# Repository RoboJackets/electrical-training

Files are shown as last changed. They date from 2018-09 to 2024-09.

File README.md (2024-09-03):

# RoboJackets Electrical Training

**Please bookmark this page!**

**Also, be sure to visit the RoboJackets Firmware Training page as well:** https://github.com/RoboJackets/firmware-training

Welcome to the source repository for the 2024 RoboJackets Electrical training program!

## Training Schedule 2024

* Time: 6:00pm - 7:30pm on Mondays and Fridays
* Bring: Your computer

Here is a breakdown of what electrical training is week-to-week:
* Week 0: Introductions, Electrical Basics*
* Week 1: Introduction to Prototyping and Arduino*
* Week 2: KiCAD Parts and Libraries
* Week 3: KiCAD Schematics
* Week 4: KiCAD Board Layout
* Week 5: Debugging and Soldering*

NOTE: Weeks 0, 1, will be joint sessions between electrical and firmware. Week 5 is a special session, usually held in the Hive. You get to practice surface mount soldering and debugging firmware on an actual PCB.

Location: 
* Week 0 (9/9 and 9/13): Van Leer C457
* Week 1 (9/16 and 9/20): Van Leer C457
* Week 2 (9/23 and 9/27): Skiles 169
* Week 3 (9/30 and 10/4): Skiles 169
* Week 4 (10/7 and 10/11): Skiles 169
* Week 5 (Date TBD): The Hive

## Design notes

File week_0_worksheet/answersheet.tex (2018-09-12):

\documentclass{article}
\usepackage{geometry}
\usepackage{flafter}
\geometry{letterpaper, portrait, margin=1in}

\usepackage{hyperref}
\hypersetup{
    colorlinks=true,
    linkcolor=black,
    filecolor=magenta,
    urlcolor=blue,
}

\usepackage{graphicx}
\graphicspath{ {images/} }

\usepackage{tcolorbox}
\usepackage{textcomp}
\usepackage{gensymb}
\usepackage{indentfirst}

\newcommand{\ans}{$\rule{1.5cm}{0.15mm}$}

\title{RoboJackets Electrical Training Week 0 Worksheet - Answer Key}
\author{Alex Xu \\ Joe Spall}
\date{\today\\v1.1}

\begin{document}
\maketitle{}
\setcounter{tocdepth}{2}
\tableofcontents

%Add Preface here

\pagebreak

\section{Introduction}
This is the Answer Key to the Week 0 worksheet. Only look at this sheet after you have given an honest attempt at \textbf{ALL} the questions. If you do not understand something from the worksheet, refer to your training instructors, classmates, and the additional information sheet provided.

\section{Intro to Electricity}
\begin{enumerate}
	\item Measured in Ohms ($\ohm$)
	\item $-3.3V-(-5V)=1.7V$
	\item Series, Parallel. Ammeter needs to be in series otherwise it will be shorted. Voltmeters essentially have infinite resistance and if placed in series will make the circuit an open circuit.
	\item $R=V/I=5V/0.2A=25\ohm$
	\item $P=V\dot I = 5V \times 0.2 A = 1W$
	\item $470\ohm \pm 5\%$
\end{enumerate}

\section{Capacitors and Inductors}
\begin{enumerate}
	\item Measured in Faraday ($F$)
	\item $C=Q/V=0.0025C/5V=0.0005F$
	\item False. Electrolytic capacitors have electrolytes inside and have polarity.
	\item False. Electrolytic capacitors are easier to achieve a higher capacitance than ceramics.
	\item Mitigating fluctuation in power supply.
	\item Henry ($H$)
	\item True. For example in solenoids and relays.
	\item False. Inductors are wires wrapped around a coil and display no special characteristics with DC.
\end{enumerate}

\section{Diodes and FETs}
\begin{enumerate}
	\item $5V/20mA=250\ohm$
	\item True. Lots of motors run at 12V and 24V and draw a lot of current while usual logic circuits runs at 5V or 3.3V and below with a very low current rating. Using FETs enables a logic circuit to use minimal power to control the flow of larger power.
	\item Q equals Vss. When A equals Vdd. The upper pFET opens and the lower nFET closes, connecting the output to ground.
\end{enumerate}

\section{Circuit Analysis}
\subsection{Parallel and Series}
	\begin{enumerate}
		\item $R=1/(1/(1.2\ohm+1.2\ohm)+1/3.6\ohm)=1.44\ohm$
		\item $ECHO\_OUT=91\ohm/(91\ohm+47\ohm)\times ECHO\_5V\approx 3.297V$
		\item $\Sigma C=(10\mu F+20\mu F+22\mu F+100\mu F)=152\mu F$
		\item $\Sigma C=1/(1/10\mu F+1/20\mu F+1/22\mu F+1/100\mu F)\approx 4.8672\mu F$
	\end{enumerate}
\subsection{Kirchoff's Law}
	\begin{enumerate}
		\item Let $i_1$ be the current going clockwise in the left loop, $i_2$ be the current through, $R_2$ from top to down and $i_3$ be the current going anti-clockwise in the right loop, then: \par
		$12V = 4\ohm \times i_1 + 3\ohm \times i_2$\par
		$8V = 2\ohm \times i_3 + 3\ohm \times i_2 $\par
		$i_1+i_3=i_2$\par
		solve for $i_1$, $i_2$ and $i_3$, get $i_3 \approx 2.15A$
	\end{enumerate}
	
	\begin{figure}[!h]
		\center
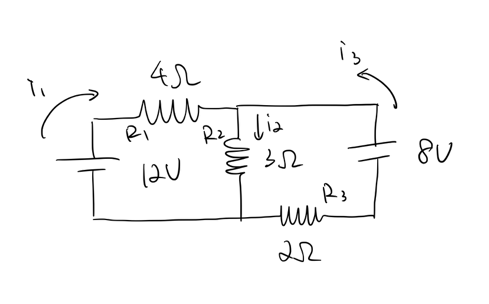
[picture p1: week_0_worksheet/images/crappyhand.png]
		
		\caption{Annotated Circuit}
		\label{fig:kirchoff_hand}
	\end{figure}

\section{Prototyping}
\begin{enumerate}
	\item Not connected, Connected, Not connected
	\item Single-core wire, should not. Twisting the wire essentially made the wire into single-core and made metal crimps harder to grab onto the wire.
	\item Pull-up resistor. To eliminate high impedance.
	\item False. This is a common joke in electrical engineering. The purpose of the fuse is to break to prevent high current levels from damaging the wires.
\end{enumerate}
\end{document}

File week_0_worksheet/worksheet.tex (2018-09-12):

\documentclass{article}
\usepackage{geometry}
\usepackage{flafter}
\geometry{letterpaper, portrait, margin=1in}

\usepackage{hyperref}
\hypersetup{
    colorlinks=true,
    linkcolor=black,
    filecolor=magenta,
    urlcolor=blue,
}

\usepackage{graphicx}
\graphicspath{ {images/} }

\usepackage{tcolorbox}
\usepackage{textcomp}
\usepackage{gensymb}
\usepackage{indentfirst}

\newcommand{\ans}{$\rule{1.5cm}{0.15mm}$}

\title{RoboJackets Electrical Training Week 0 Worksheet}
\author{Alex Xu \\ Joe Spall}
\date{\today\\v1.1}

\begin{document}
\maketitle{}
\setcounter{tocdepth}{2}
\tableofcontents
\pagebreak

\section{What is this worksheet? What's so special about it? Why should you read it?}
There are three documents in the Week 0 training: a worksheet, its answer sheet and an informational sheet that explains everything in this document. This document is the worksheet.
\vspace{6pt}\par
RoboJackets build robots, and we are going to help you understand how we built them so you can do it as well. The electrical training focuses on the idea of ``Prototyping", which requires a basic understanding of electricity. We therefore prepared Week 0 session for those have little knowledge in electricity so you'll walk in to Week 1 less confused. \vspace{6pt}\par
This worksheet contains all \textbf{a variety questions pertaining to information you should know when you walk into Week 1} electrical training session. It is perfectly fine if you do not know certain, or any, concepts covered in this worksheet. If there are any concepts in this worksheet you do not feel comfortable with, please ask any of the instructors or your classmates for help. For more background on the topics, you can also refer to the Informational Sheet. Please only refer to the Answer Sheet after you have attempted to answer all of the questions.\vspace{6pt}\par

\section{Intro to Electricity}
\begin{enumerate}
	\item Resistance is measured in \ans. (Unit)
	\item If the two terminals of a resistor are measured to be -3.3V and -5V with reference to some arbitrary pre-defined ground. The potential difference across the resistor is \ans.
	\item To measure current,an Ammeter is connected in \ans\ (parallel / series) with the desired path. To measure voltage, a Voltmeter is connected in \ans\ (parallel / series) with the desired path.
	\item 5V is applied across a resistor and the resultant current is 0.2A. The resistance across the resistor is \ans.
	\item The resistor in the previous question is dissipating energy at \ans W.
	\item With reference to the color coding diagram (Figure \ref{fig:Resistor}), a resistor of yellow, violet, brown and gold color code has a resistance of \ans.
	\begin{figure}
		\center
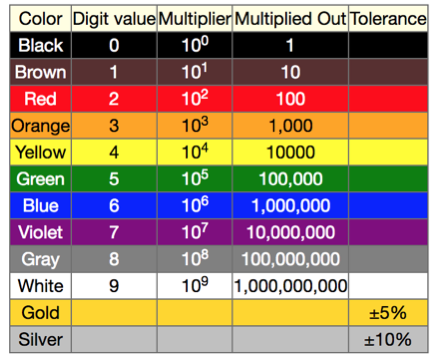
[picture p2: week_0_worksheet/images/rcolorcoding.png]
		
		\caption{Resistor Coding Chart}
		\label{fig:Resistor}
	\end{figure}
\end{enumerate}

\section{Capacitors and Inductors}
\subsection{Capacitors}
\begin{enumerate}
	\item Capacitors are measured in \ans. (Unit)
	\item 0.0025 coulomb of charge accumulates across a capacitor when 5V is applied, its capacitance is \ans.
	\item There are two types of capacitors: ceramic and electrolytic. Both of them do not have polarity (True / False).
	\item Electrolytic capacitors usually have a lower value than ceramic capacitors. (True / False)
	\item Capacitors are used in circuits for what purposes related to power?
\end{enumerate}
\subsection{Inductors}
\begin{enumerate}
	\item Inductors are measured in \ans. (Unit)
	\item Inductors can typically be found in electro-mechanical parts on a robot. (True / False)
	\item An ohmmeter is connected across an inductor and the meter reads zero ohms. The inductor is definitely broken. (True / False)
\end{enumerate}

\section{Diodes and FETs}
\begin{enumerate}
	\item LEDs are a type of diode, and they're very delicate. We need to apply additional resistors in series to an LED to prevent too much current. If the supply voltage is 5V and the LED is rated at 20mA maximum, what's the minimum resistance of the additional resistor?
	\item FETs are used to help low voltage logic circuits to control high voltage and current-drawing motors. (True / False)
	\item For the Figure \ref{fig:transistor}, assume the two transistors are functioning properly with respect to Vdd and Vss levels. What's the voltage level of Q when voltage at A equals Vdd?

	\begin{figure}[!h]
		\center
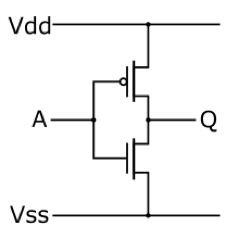
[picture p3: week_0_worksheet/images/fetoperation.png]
		
		\caption{Transistor Operation Schematics}
		\label{fig:transistor}
	\end{figure}
\end{enumerate}
\clearpage
\section{Circuit Analysis}
\subsection{Parallel and Series}
\begin{enumerate}
	\item Two $1.2 k \ohm$ resistors are in series, and this combination is in parallel with a $3.3 k\ohm$ resistor (left circuit in Figure \ref{fig:parallel}). The total resistance is \ans.
	\item Consider the right circuit in Figure \ref{fig:parallel}. Assume ECHO\_5V is actually 5V. What's the voltage at ECHO\_OUT?
	\item A $10 \mu F$, $20 \mu F$, $22 \mu F$, and $100 \mu F$ capacitor are in parallel. The total capacitance is \ans.
	\item Now the capacitors in Q3 are in series. Their capacitance is \ans.
	
	\begin{figure}[h]
		\center
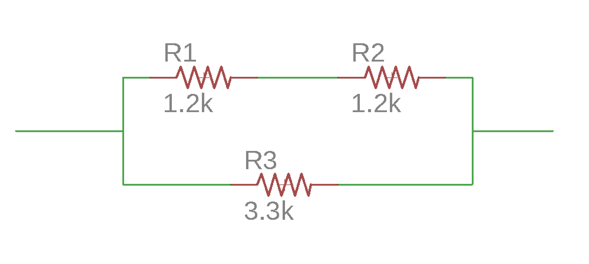
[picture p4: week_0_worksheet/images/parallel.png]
		
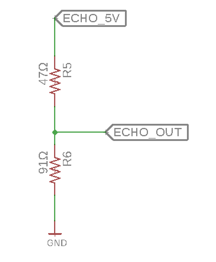
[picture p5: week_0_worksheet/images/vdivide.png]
		
		\caption{Parallel and Series Analysis}
		\label{fig:parallel}
	\end{figure}

\end{enumerate}
\subsection{Kirchoff's Law}
\begin{enumerate}
	\item In Figure \ref{fig:kirchof}, $R_1=4\ohm ,R_2=3\ohm,R_3=2\ohm, \varepsilon_1=12V, \varepsilon_2=8V$. What's the current through $ R_2 $.
	\begin{figure}[!h]
		\center
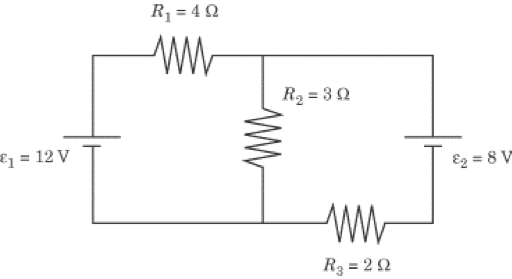
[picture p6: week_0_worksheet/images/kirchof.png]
		
		\caption{Kirchoff's Circuit Analysis}
		\label{fig:kirchof}
	\end{figure}
\end{enumerate}
\clearpage
\section{Prototyping}
\begin{enumerate}
	\item Breadboards are very useful during prototyping. If the breadboard in front of you is oriented so that the longer side faces you (see Figure \ref{fig:bread}). Holes in the same rows are \ans\ and those in the same column are \ans. Columns on the two sides of the middle trench are \ans\ (Fill in with Connected or Not connected). 
	\item When prototyping with breadboard, you should use \ans\ (single-core / multi-core) for a signal line. When crimping a multi-core wire, one (should / should not) twist the wire to make it more solid. 
	\item Is R1 in the right-sided circuit of Figure \ref{fig:bread} acting as a pull-down resistor or pull-up resistor? What does it do?
	\begin{figure}[h]
		\center
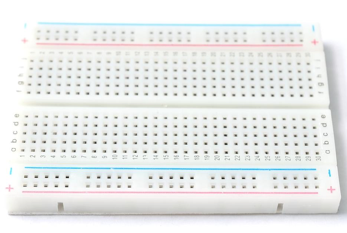
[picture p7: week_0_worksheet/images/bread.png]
		
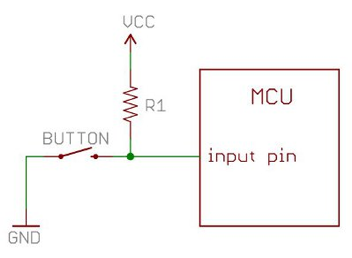
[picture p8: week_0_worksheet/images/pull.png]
		
		\caption{Example breadboard and pull-up resistor network}
		\label{fig:bread}
	\end{figure}
	\item Fuse is the most fragile part of your circuit. Replace it with a wire to make your circuit more robust (True / False).
\end{enumerate}
\end{document}

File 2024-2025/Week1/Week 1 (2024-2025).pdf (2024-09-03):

# Welcome!

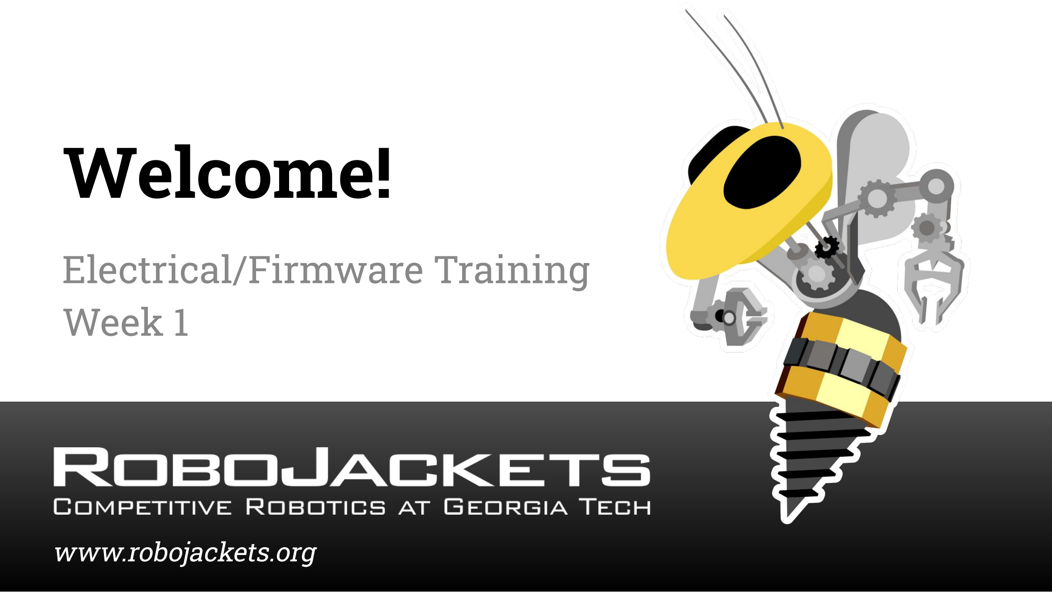
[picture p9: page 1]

## www.robojackets.org

# Electrical/Firmware Training Week 1

# - Introductions

# - What is RoboJackets Electrical/Firmware?

# - Logistics

# - Electrical Basics

# Last Week!

# This Week!

# - Microcontrollers & Firmware

# - Arduino, Part 1

# - Prototyping

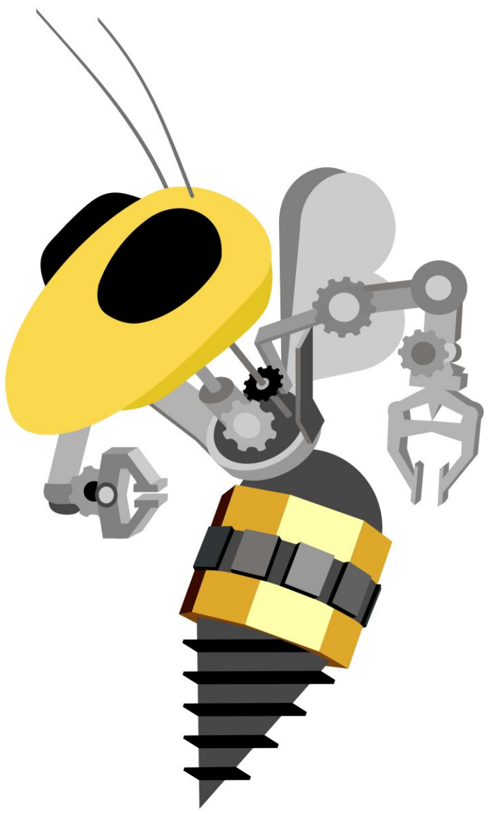
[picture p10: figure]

# Microcontrollers and Firmware

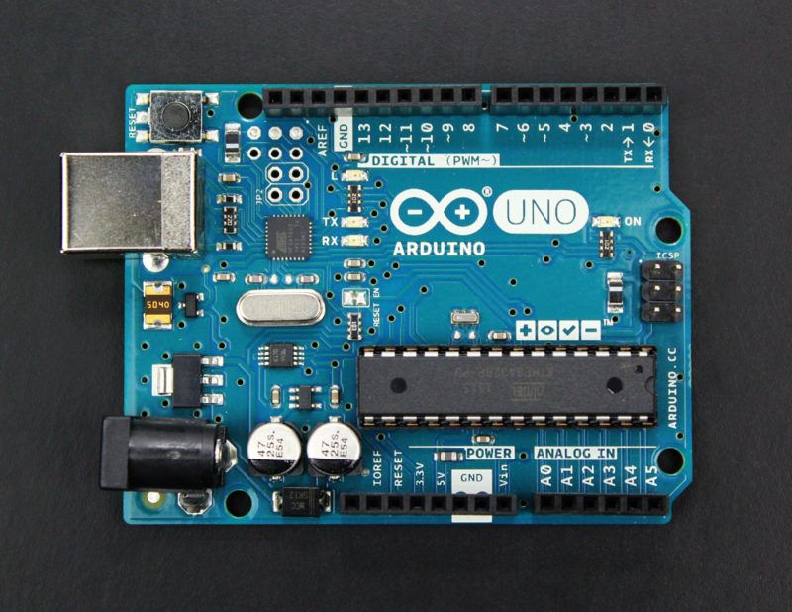
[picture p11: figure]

## - Arduino is…

- … a development board
(Arduino Uno, Arduino
Nano)
- … a programming
language (libraries,
compiler, syntax)

## - Development board centered around microcontroller

# Arduino!

# Programming a MCU

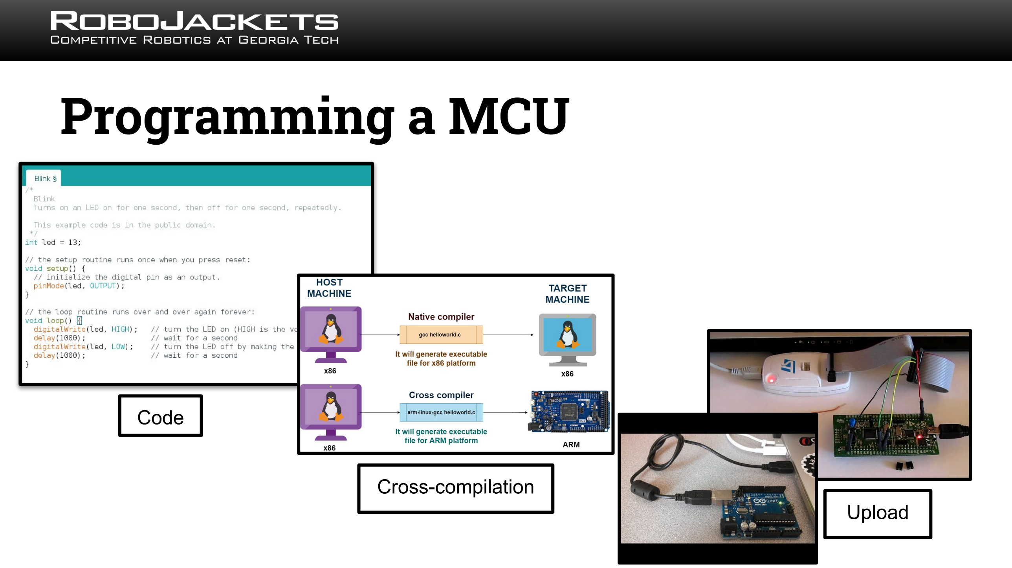
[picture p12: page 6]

Code

Cross-compilation
Upload

# Example: RoboWrestling

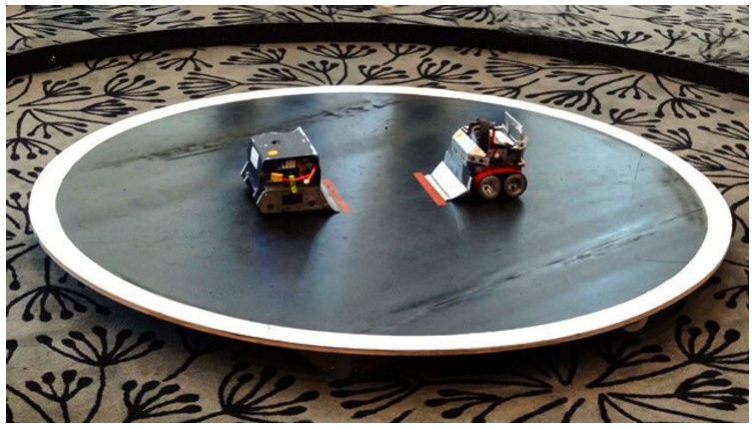
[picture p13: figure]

# High-level Decisions (Software)

- Where am I in the dohyo (ring)?
- Where is my opponent?
- Where should I move?
- If I made contact with the opponent, what should I do?

# Example: RoboWrestling

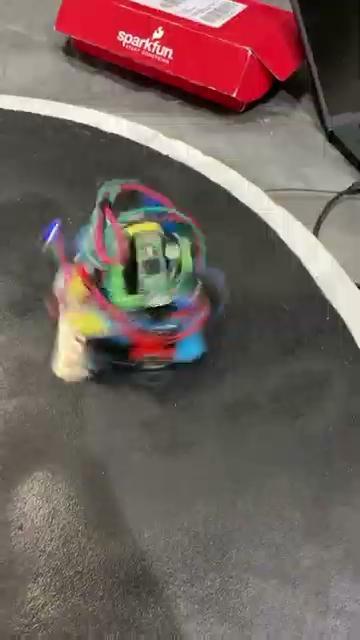
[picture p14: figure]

# Low-level Decisions (Firmware)

- How do I instruct the motors to spin at the desired speed?
- How do I instruct the robot to start?

## - Speed

- Counting encoder ticks <<< Computer vision algorithm

## - Space

- MCUs are small, PCs are not

## - Overkill

- Some robots don’t need to make complicated decisions
- PC would be $$$ to replace

## - Convenience

- Robotics hardware + software APIs cater to MCUs

# Why aren’t Low-level decisions made by a “software computer?”

# Prototyping

# Breadboard and Arduino Uno

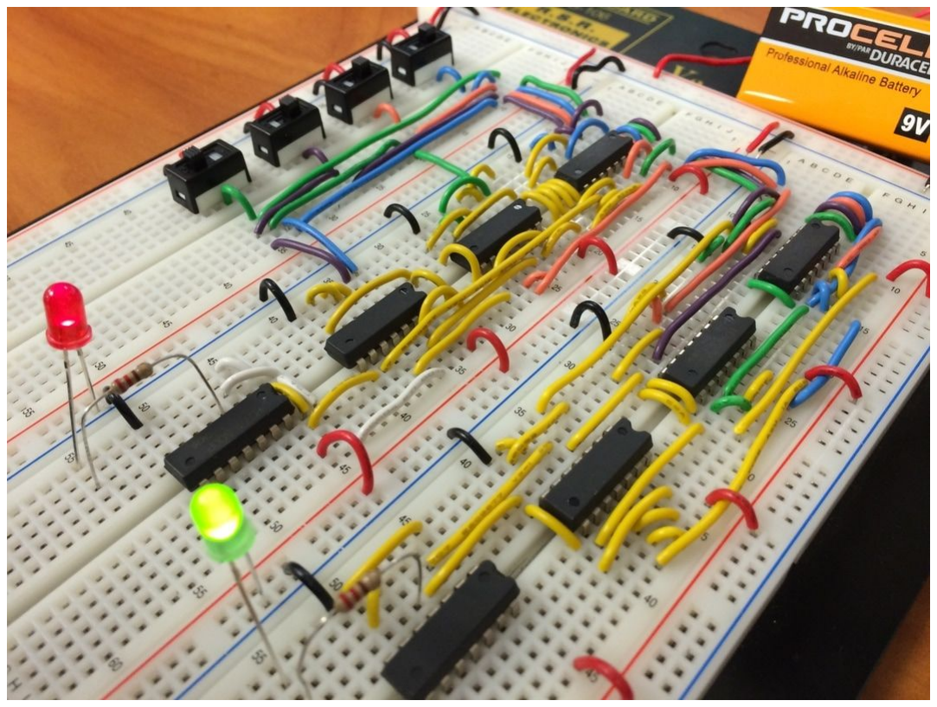
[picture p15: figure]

## - Solderless Breadboard (Top)

- Easy to change
- Good for initial prototyping
- Difficult to build large circuits

## - Protoboard (Middle)

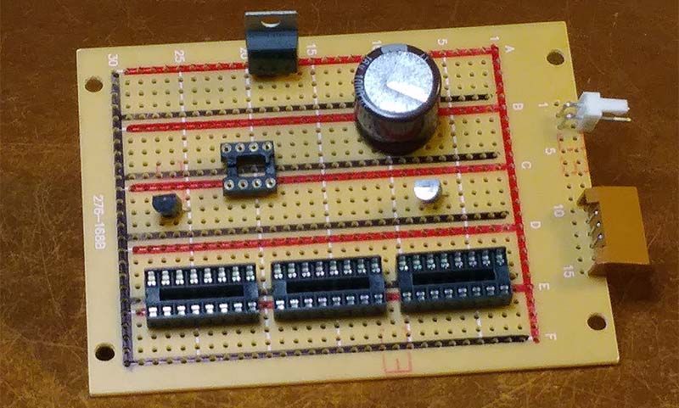
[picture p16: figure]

- More permanent; solder used
- Good for mature prototype
- Changes are doable, but involves re-soldering

## - Printed Circuit Board (Bottom)

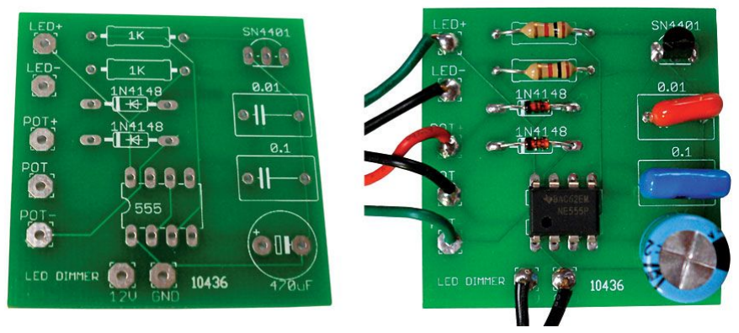
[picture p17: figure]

- Most permanent; unable to change connections
- Able to tightly pack components
- Circuit can span several layers
- Good for finished product

# From Breadboard to PCB

# Prototype basic circuit designs with Breadboards

Breadboards help you connect electrical components to build basic circuits.

### Terminals are the vertical columns. Each terminal is independent from the other

### Power rails are use to connect the power supply to the breadboard. The horizontal

pins on each power rail are connected.

Top half and bottom half of the breadboard are independent from each other.

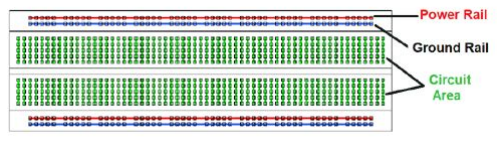
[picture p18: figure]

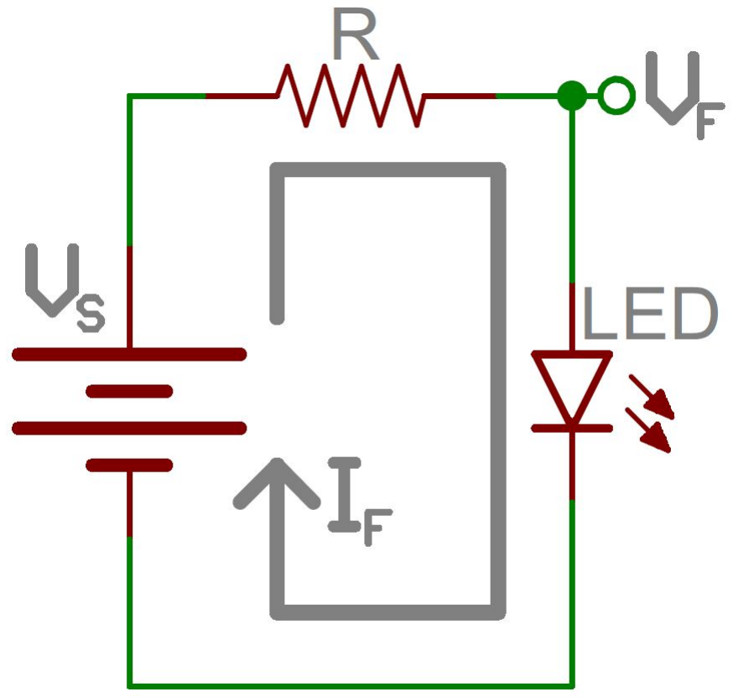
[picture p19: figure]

## - LEDs

- Diode: allows lots of current in one direction
- LED: too much current = blow up

## - Buttons

- Open / close a circuit
- Problem: High Impedance / “floating” pin

## - Resistors

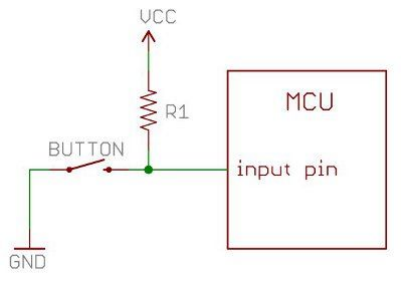
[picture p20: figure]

- Current-limiting resistor + LEDs (I = V / R)
- Pull-up resistor + Buttons

# Prototyping Hardware

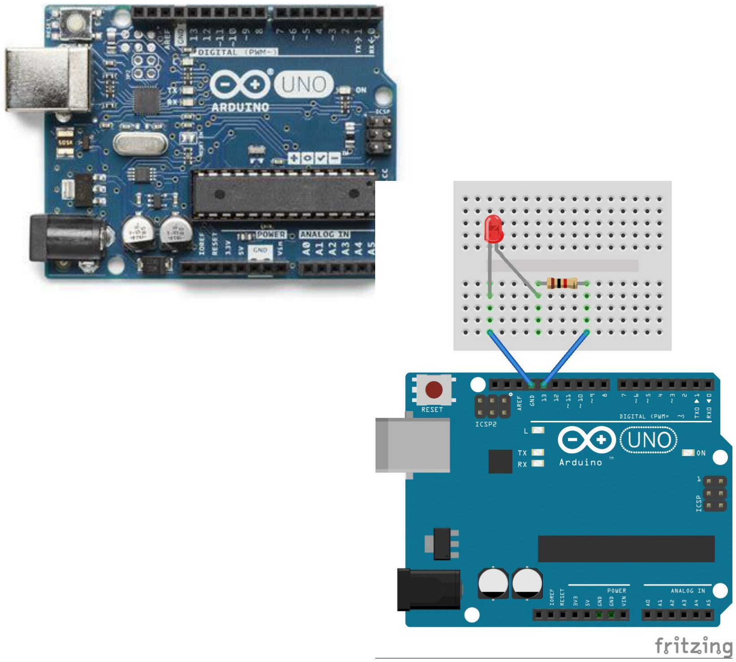
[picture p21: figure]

# Arduinos!

# Microcontroller with I/O ports to control electronics

# The pinout diagram

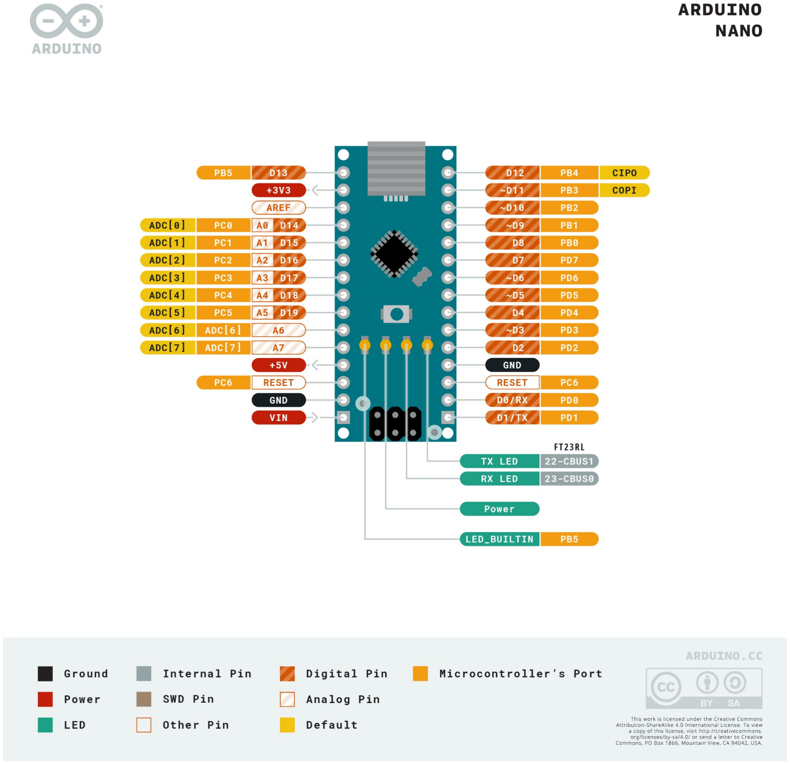
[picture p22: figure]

## - Arduino Nano Pinout - Physical pins -> software pins - Ex: D2 (hardware ) - -> “2” (software) - Some important pins:

## - PWM#: Digital (0 or 1) - A#: Analog (not restricted to 0 or 1) - VIN: Input voltage - If you’re not sure what a pin does, read the datasheet!

# Arduino IDE Explained

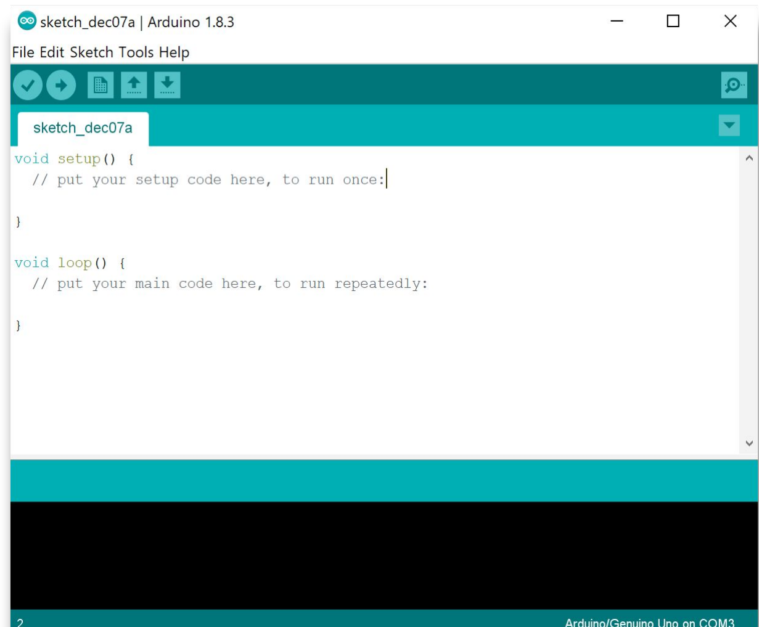
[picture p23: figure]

Verify checks for errors and compiles code

Upload compiles and uploads code

New creates new sketch

Save saves your sketch

### - IDE = “Integrated Development Environment”

- Programs = “sketches”.

Serial Monitor displays print outputs

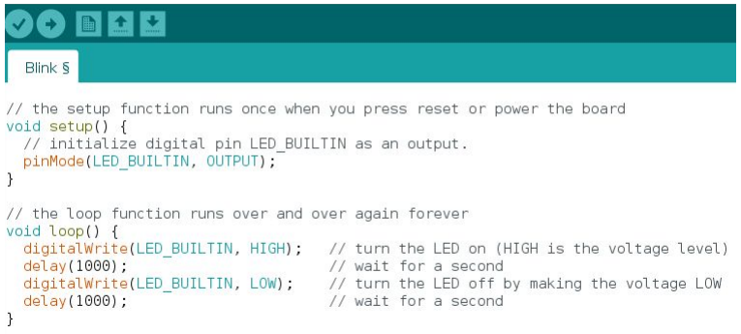
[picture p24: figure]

# - setup()

# - loop()

# - pinMode()

# - digitalWrite()

# - delay()

# Blink Example

# StateChangeDetection, Part 1


# - Variables

- Pin variables (buttonPin, ledPin)
- Integer variables

(buttonPushCounter, buttonState,

lastButtonState)

# - pinMode()

# - Serial.begin()

# StateChangeDetection, Part 2


# - digitalRead()

# - If /else

# - digitalWrite()

# Lab

# LEDs and Buttons

# Lab Time!


# - Read the lab setup

## - Legacy Arduino IDE - CH340 drivers - Challenges! - Blink - Blink + Button - Variable Frequency Blink + Button - Binary Counter

## Bring the following: - Laptop - Mouse (highly recommended unless you’re a menace with trackpad) - A Coke for Kyle

## Location: - Firmware: Skiles 255 (Monday) and Van Leer 457 (Friday) - Electrical: Skiles 169 (Monday and Friday)

# For next time…

# Feedback/Attendance


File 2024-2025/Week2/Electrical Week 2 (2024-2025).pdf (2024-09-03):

# Welcome!


www.robojackets.org

# Electrical Training Week 2

- What are Microcontrollers?
- Intro to C++
- Prototyping

# Last Week!

- Introduction to PCBs
- Introduction to KiCAD
- Parts and Libraries in KiCAD
- Configuring KiCAD Setup
- Adding parts to KiCAD

TLDR, we are going to import our parts into KiCAD from SnapEDA.

# This Week!

# What are PCBs?

# Printed Circuit Boards (PCBs)


- A way to construct more
electrically complex circuits
that are impractical for a breadboard
- Have a wide range of
components (sensors, MCUs, power circuit components)
that are often surface mount (SMD) rather than through
hole

Through Hole


Surface Mount

# Team


# Examples

## We use PCBs for a wide range of problems

# What is KiCAD?

## Where the suffering begins

# KiCAD


- Computer software to design PCBs
- Three Stages of Development
- Libraries & Parts (focus on this today!)
- Schematics
- Board Layout

# Project Manager


• Store various components used in projects • Schematic and footprint libraries are separate for electrical components in KiCAD • We will focus on the schematic library today; Libraries; Schematic; Library; Footprint Library


- Used in the schematic
view to make circuit
connections with other
component symbols
- “Symbolizes” the
connections made on the
PCB

# Symbol


- Used in the the board
layout view to make the
actual physical
connections between
components
- The component will
actually somewhat look
like the footprint

# Footprint


# Lab!

## KiCad Setup + Adding Parts to Schematic/Footprint Library

# Installing Software

- KiCAD
- Download here
- https://www.kicad.org/download/

- You could make your own parts, but why do that when someone else has already done it?
1. Go to snapeda.com (make an account if you haven’t done so)
2. Search up your part
3. Download the symbol and footprint and click the KiCad option
4. Inside the zip folder, there is a tutorial on how to import the symbol, follow the instructions for KiCad (or click on this link) (https://www.snapeda.com/about/import/#KiCad6)
- You will have to import the symbol and footprint separately
- Note: For footprint, you select the folder, not an actual file

# Downloading Parts from SnapEDA

- watch me embarrass myself

# Live Demonstration


- There are other symbol/footprint websites out there, so look around the internet!
- If you genuinely cannot find it, you can make your own inside KiCAD
- It’s a little advanced and somewhat niche, so I will not be going over it, but here is a link (https://github.com/RoboJackets/electrical-training/blob/master/labs/Week%202%20Lab%20(2023-2024).pdf) if you’re interested

# What if I can’t find my part?

# Thank You!

## Any Questions?

# For next time…

KiCAD Schematic! Be sure to bring:
- Your laptop
- Mouse (highly recommended)
- A Coke for your instructor (me)

Location:
- Electrical: Skiles 169
- Firmware: Van Leer C457

# Feedback/Attendance


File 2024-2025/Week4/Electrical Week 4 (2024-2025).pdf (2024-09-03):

# Welcome!


www.robojackets.org

# Electrical Training Week 4

# Last Week!

- Communication Systems
- KiCAD Schematics

1. Recap
2. Board Layout
a. Layers
b. Arranging components
c. Routing
d. Polygons
e. Lab!

# This Week!

- Previously studied Parts/Libraries and Schematics
- There are separate symbol and footprint libraries
- In schematics, we use nets to link pins on a symbol together to represent a device’s function

# Recap

# Board Layout


www.robojackets.org

# Place and route

- Physical placement of components on the PCB
- Replace the abstract nets from schematic with physical traces
- Access this feature by pressing the “Open PCB in board editor” button at the top of your schematic window or opening the PCB editor from the Project Manager window

# Board Layout

# PCB Structure

Copper; Soldermask; Silkscreen; Pads

Color | Layer Name | Layer Purpose
| F.Cu | Top/front layer of copper
| B.Cu | Bottom/back layer of copper
| Edge.Cuts | Outline of the board
| F.Silkscreen | Silkscreen for top
| B.Silkscreen | Silkscreen for bottom
| F.Fab | Top/front documentation layer (just for reference)

NOTE: Pads (SMD and through-hole) are part of footprints and vias are not part of any layer


# Changing Layers

## Select the layer you want to edit

# Assign


# Footprints to Symbols

## This must be done from the Schematic Editor

# Assign Footprints to Symbols

1. At the top, click Tools -> Assign Footprints
2. Match the schematic symbol to the PCB footprint that you want
- You can search the footprint you want in the search bar
- KiCAD doesn’t have the footprint for all parts, so you will have to download them from SnapEDA or make them yourself beforehand

## This is in the PCB Editor

# Board


# Generation


- Click on part and drag to move parts around
- Press ‘R’ to rotate
- Position components on the board area

# Arranging Components

- Minimize airwires (the unrouted wires)
- Collection of all airwires is ratsnest
- Maximum size of board
- Clearance between mounting holes and components
- Location of specific components
- Connectors on board edge
- Decoupling capacitors near decoupled pins
- Communicating/related components near one another

# Arrangement Considerations


- Leave some space
- Room for traces
- Room to solder
- Minimize the number of
intersecting airwires
- Easier to route traces

# Arranging Components


- Use the Route tracks
command in the right bar
- Left click on starting
point and left click on
end point
- Follow start and end of
airwire
- Routing angle of 45
degrees

# Drawing Traces


- Press “v” to change the
layer and put a via
- You can also right click, then click on “Place a
via”

# Changing Layers


- Allows you to fill a drawn area with copper connected to a specific net
- Useful to make “ground
planes”
- Click on “Add a filled zone”
- Then draw a shape such
as a rectangle or polygon
- Fill the polygon with Edit > Fill All Zones

# Filled Zone

Design Rules
Predefined rules that your board layout should follow to be correctly manufactured.
DRC (Design Rules Checker)
This tool will check if your board layout is attending to all of the design rules and notify you accordingly.

Note: Load Design Rules early on your design.

# Design Rules and DRC


Preview
- Make sure the silkscreen looks good (Both top and bottom side) Board
- Shows board properties: height, width, area, layers, board thickness, etc

# Gerber Viewer

- Start a new board layout
- Set up the dimensions
- Arrange the components
- Connect the traces
- Touch-up the silkscreen
- Check your design with DRC

For more information, access the LAB Document on GitHub.

# Lab Summary

- Watch me embarrass myself

# Live Demonstration


KiCad Getting Started:
https://docs.kicad.org/7.0/en/getting_started_in_kicad/getting_started_in_kicad.html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 (https://docs.kicad.org/7.0/en/getting_started_in_kicad/getting_started_in_kicad.html) How to branch on GIT:
https://github.com/RoboJackets/robocup-firmware/blob/master/doc/Git.md (https://github.com/RoboJackets/robocup-firmware/blob/master/doc/Git.md)

# Resources

We will be soldering! Please bring the following things:
- Yourself
- Computer/Laptop
- A Coke for Kyle

Location: The HIVE
When: TBD (sorry)

# For next time…

# Feedback/Attendance


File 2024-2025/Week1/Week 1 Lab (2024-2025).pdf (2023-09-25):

# RoboJackets Electrical / Firmware Training Week 1

Andrew Roach

September 25, 2023
v1.1

## Contents

1 Before You Start | ii
2 Background | iii
3 Objective | vii
4 Appendix | ix

i

## 1 Before You Start

### 1.1 Prerequisites

Before diving into the lab, make sure you have followed the Setup Instructions, which can be found on the RoboJackets Electrical Training GitHub page. After completing the setup instructions, verify that you have the following:

- The Legacy Arduino IDE (version 1.8.X, NOT 2.X!).
- A working Arduino Nano. When you plug the Nano into your computer, the LED labeled “POW” should illuminate.
- The CH340 drivers. If you installed the drivers correctly, the Arduino Nano should appear when you click on Tools > Port in the Arduino IDE.

### 1.2 Setup

Before you can upload code to the Arduino Nano, you need to tell the Arduino IDE what hardware you are using. To configure this, set the following settings in the Tools menu:

- Board: Arduino Nano
- Processor: ATMega328P (Old Bootloader)

– If this fails, try ATMega328P

- Port: select the port the Arduino Nano is plugged into.

– On Windows, check the “Ports” section in Device Manager

– On Linux, check for devices starting with /dev/ttyACM* or /dev/ttyUSB*.

- Programmer: AVPISP mkII


Figure 1: A properly configured Arduino IDE. Note that the “Port” value will be different.

ii

## 2 Background

The goal of this lab is to get you acquainted with prototyping with Arduinos. First, you must understand the hardware you are working with. Next, you will learn how to write and upload software onto an Arduino. Finally, we will give a brief introduction into the Arduino programming language. At the end, you will be tasked with implementing some basic circuits involving LEDs, resistors, and pushbuttons.

### 2.1 The Arduino Nano

Figure 2 depicts the pinout diagram for the Arduino Nano. The pinout diagram summarizes the capabilities of the Arduino Nano and depicts the mapping between the physical pins on the microcontroller and the aliases given to the physical pins in software. For example, the digital pin “D2” is represented by the integer “2” in an Arduino program.
For this lab, we will be primarily focused on the digital pins, D0 - D19. The digital pins operate in a binary fashion; they send and receive signals as a logical HIGH or a logical LOW. Since the Arduino Nano operates on 5V logic, logical HIGH corresponds to 5V, while logical LOW corresponds to 0V.


Figure 2: Pinout for Arduino Nano. The “Digital Pin” numbers (D2, D3, etc...) correspond to the numbers used in functions such as pinMode and digitalWrite.

iii

Figure 2 also depicts some pins that can’t be interacted with via software, but are useful nonetheless. The +3V3 and +5V pins provide power, while the GND pins provide a ground reference. The VIN pin stands for “Voltage In”, and it is used to supply 5V externally when you aren’t providing the microcontroller power over USB. The “Reset” pins are used to restart the program on the Arduino Nano using an external signal.
The Arduino Nano also has some useful features besides its pins. The button in the middle of the Arduino Nano causes the program on the Arduino Nano to restart. The “Power” LED illuminates when the Arduino Nano is being powered by 5V. The LED labeled “LED BUILTIN” is an LED that can be controlled via software. You can address it using the LED_BUILTIN macro in your program.

### 2.2 Electrical Hardware

The solderless breadboard shown in Figure 3 is your workspace when prototyping. The power rails labeled with “+” and “-” are connected horizontally and is ideal for distributing 5V and GND. The terminal strips in the middle of the solderless breadboard are connected vertically. The center divider separates the terminal strips on either side of breadboard from one another.
Jumper wires are useful for carrying electrical signals between different vertical terminal strips or between the power rails and the vertical terminal strips. Resistors are useful in conjunction with LEDs and pushbuttons. LEDs will burn themselves out if they are given too much current. The voltage drop across an LED is constant, so by increasing the resistance of the LED by using a resistor in series with an LED, the current drops. Resistors are also used with buttons to ensure the output of the button is never floating. See the appendix for more details.


Figure 3: Anatomy of a solderless breadboard.


Figure 4: An example of how to lay out a circuit on a breadboard. The Arduino Nano straddles the center divider, providing power to the power rails. The resistor, LED, and button are laid out across different terminal strips and are connected using jumper wires.

iv

### 2.3 The Arduino IDE

We will summarize a couple of important features for getting started with the Arduino IDE.

### 2.3.1 Sketches and Examples

User-created programs in the Arduino IDE are called sketches. The Arduino IDE also provides some built-in example sketches under File > Examples. Some useful examples for this lab are “Blink” under “Basics” and “Button” under “Digital”. You cannot modify examples, but you can use them as a starting points for your sketches.


Figure 5: Accessing the Arduino IDE’s built-in examples under File > Examples.

### 2.3.2 Verifying and Uploading Code

Once you have written your Arduino program, you have to do two things before your code is running on the Arduino Nano.

- Verify (checkmark button): This compiles your code into an executable format for the microcontroller. Compilation will fail if you have made a syntax error in your program. You do not need to be plugged into the microcontroller to Verify your program.
- Upload (arrow button): This uploads your code onto the microcontroller plugged into your computer. Uploading may fail if your settings in the “Tools” menu is incorrect; if you are having issues uploading to the microcontroller, go back to Section 1.2 and verify your settings are correct! The program will begin running immediately after it finishes uploading.

Figure 6: The Verify (checkmark) and Upload (rightward-facing arrow) buttons in the Arduino IDE.

v

### 2.3.3 The Arduino Programming Language

The Arduino Programming language is similar to C++. Below, we have listed some useful functions for this lab:

- setup(): setup() is called when the program starts. It will run once when you power on or reset the Arduino. setup() is ideal for initializing variables and setting pin modes.
- loop(): This function loops consecutively so the code you place here will constantly run. You can have other functions in your program but they will not run unless they are called in setup() or loop().
- pinMode(pin, mode): Configures pin to behave as input or output.

– Example 1: pinMode(2, OUTPUT) configures pin D2 on the Arduino Nano as an output.

– Example 2: pinMode(7, INPUT) configures pin D7 on the Arduino Nano as an input.

– Example 3: pinMode(LED_BUILTIN, OUTPUT) configures the built-in LED of the Arduino Nano as an output.

- digitalWrite(pin, value): Writes a HIGH or LOW value to a digital pin.

– Example 1: digitalWrite(2, HIGH) drives pin D2 to logical high (5V on Arduino Nano)

– Example 2: digitalWrite(2, LOW) drives pin D2 to logical low (0V on Arduino Nano)

– Example 3: digitalWrite(2, 1) drives pin D2 to logical high (5V on Arduino Nano)

- digitalRead(pin): Reads a value (HIGH or LOW) from a digital pin.

– Example 1: int buttonVal = digitalRead(7) reads a digital value (HIGH=1 or LOW=0) from pin D7 into the variable buttonVal.

- delay(time): Pauses the program for a number of milliseconds.

– Example 1: delay(500) pauses the program for 500 milliseconds.

If you need information or examples on how the Arduino programming language works,

- Check out the Arduino Language Reference. (https://www.arduino.cc/reference/en/)
- Refer to the Arduino IDE’s built-in Examples under File > Examples.

vi

## 3 Objective

Here are some challenges for you to try out!

### 3.1 Uploading Blink

- Open up the example Blink program under Files > Examples > Basics > Blink.
- Verify and Upload the Blink program.
- The Arduino Nano’s onboard LED should blink on and off.

### 3.2 Blinking an External LED

- Create a sketch that will blink an LED on the breadboard.

– Refer to the Arduino Nano’s pinout in section 2.1 to figure out which physical pins map to which numbers in software.

– You will need to use the pinMode, digitalWrite, and delay functions. Refer to section 2.3.3 to learn how to use these functions.

- You will need to put a resistor and LED in series, as shown in Figure 7.

– LEDs have polarity; current will only flow from the anode (longer, positive leg) to the cathode (shorter, negative leg).

– Provide power through your software-controlled digital output pin on the Arduino Nano, and connect the LED’s cathode (shorter, negative leg) to the Arduino Nano’s GND.


Figure 7: Example circuit diagram for blinking an external LED using an Arduino Uno. The resistor and LED are connected in series. Power is supplied through pin 13, and the LEDs cathode is connected to ground.

vii

### 3.3 Blinking LEDs using a button

- Use the digitalRead function to read the value of the button.

– To figure out how to wire up the button, refer to the Appendix.

- Try controlling two different LEDs using two different digital output pins with the button. For instance, one LED could turn on while the other turns off when the button is pressed.

### 3.4 Using button to adjust blink frequency (optional challenge)

- Use a button to control the rate at which an LED blinks.
- For instance, button unpressed = slow blink, button pressed = fast blink.

### 3.5 Binary Counter (optional challenge)

- Create a binary counter using the button as input and the LEDs as output.

– A button press increments the count by 1

– Read up on Binary number and bit masking (https://www.clivemaxfield.com/coolbeans/masking-and-the-c-c-bitwise-operators/) to figure out how to translate a number into the LED output.
– Read the Appendix section about button debouncing

viii

## 4 Appendix

### 4.1 Pull-up Resistors

Pull-up resistors (and pull-down resistors) are used to ensure that a pin is not left floating when a connection is opened (by a button in this case). We connect the output side of the circuit to power through a resistor to accomplish this. Check out the circuit below.


Figure 8: Circuit diagram of pullup resistor in use with a button. When button is unpressed, resistor “pulls up” value of input pin.

Luckily, the Ardunio Nano has built-in pull-up resistors for all its digital pins, but we must activate them in firmware. To do this, we simply change the pinMode of the pin. Instead of using pinMode(pin, INPUT), we use pinMode(pin, INPUT_PULLUP). You can read more here. (https://docs.arduino.cc/tutorials/generic/digital-input-pullup)

### 4.2 Debouncing

Due to mechanical/electrical issues, when a button is pressed it may be detected as many button presses.


Figure 9: When switch is closed (left), voltage read by the microcontroller can fluctuate for a brief period before stabilizing (right). This can make a single button press look like several button presses.

These fluctuations might be detected by the MCU as many button presses, causing issues in firmware. To counter this issue, there a few things we can do. For now, we can simply add a delay after we detect the change of state. However you decide to detect a button press to increment the binary counter, you can add a delay(50) after so that the MCU doesn’t even look for another change of state until the delay is over. 50 ms is more than enough time to counter this issue.

ix

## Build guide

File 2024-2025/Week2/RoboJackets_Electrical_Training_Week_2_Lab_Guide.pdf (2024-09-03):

# RoboJackets Electrical Training Week 2 Lab Guide

Kyle Nguyen

August 23, 2024
v1.0

## Contents

1 Background | 2
2 Initial Steps | 2
3 Materials | 2
4 Objective | 2
5 Guided Lab | 2
6 Making Your own Symbol or Footprint | 5
7 Troubleshooting | 5

## 1 Background

In the Week 2 Electrical Training lecture, you learned about PCBs, KiCAD, Libraries, and Parts. In RoboJackets, PCB design is an integral part of our autonomous teams’ electrical stack, thus if you are interested in PCB development for RoboJackets and hardware design in general, learning how to use KiCAD is essential.
In this lab, we will be focusing on downloading parts that have already been made from SnapEDA and adding them to the symbol and footprint libraries.

## 2 Initial Steps

### 2.1 Install KiCAD

- If you have not already installed KiCAD, please download it here. (https://kicad.org/download)
- Note: If you are having trouble with any of these steps please let a trainer know.

### 2.2 Create a SnapEDA Account

- Go to the SnapEDA (https://www.snapeda.com/home/) website and create an account.

## 3 Materials

- Laptop
- KiCAD (https://kicad.org)
- Recommended: An external mouse

## 4 Objective

For this lab, you will be downloading the parts to make a simple PCB for a robot. This PCB will have a microcontroller, two mechanical switches, two motor drivers, and a voltage regulator. This robot is somewhat useless, but it will provide a good introduction to how to import symbols and footprints into KiCAD from SnapEDA.

### 4.1 Parts

- Teensy 4.1 (Microcontroller) (https://www.pjrc.com/store/teensy41.html)
- Cherry MX Black Switches (MX1A-11NN) (https://www.digikey.com/en/products/detail/cherry-americas-llc/MX1A-11NN/91136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)
- Motor Driver (A4950ELJTR-T) (https://www.digikey.com/en/products/detail/allegro-microsystems/A4950ELJTR-T/2626338)
- Voltage Regulator (TSR 1-2450) (https://www.soselectronic.com/en/products/tracopower/tsr-1-2450-70570?gad_source=1)

## 5 Guided Lab

In the project manager of KiCAD, click on File → New Project and choose whatever project name you want. Make sure the Create a new folder for the project checkbox is ticked, then click Save. This will create your project files in a new subfolder with the same name as your project. We will be using this project for this lab, Lab 3, and Lab 4, so make sure you save it in a safe location!

### 5.1 Downloading the Teensy from SnapEDA

### 5.1.1 Searching up the Teensy on SnapEDA

- Check the Teensy 4.1 website (https://www.pjrc.com/store/teensy41.html) to find the exact name of the part.
- Copy and paste this into the search bar of SnapEDA. For the best search results, be as specific as possible!
- After hitting the search button, click on the part. Make sure the title matches the Teensy 4.1 part exactly! Also make sure that the part you are looking at includes both the symbol and the footprint for the part.
- Click on Download Symbol and Footprint, and be sure to download it for KiCAD. Extract the zip file to a safe location on your computer.

Figure 1: Teensy 4.1 search result in SnapEDA, with a red box around the symbol and footprint availability.

### 5.1.2 Importing the Symbol into the Symbol Library

Inside the folder, there is a PDF (https://www.snapeda.com/about/import/) on how to import symbols and footprints into KiCAD, but I will list them here for absolutely no reason.

- In KiCAD, go to Preferences at the top left.
- Click on Manage Symbol Libraries.
- Within Global Libraries, click on the small folder icon near the bottom left (Add existing library to table).
- Select the .kicad sym file, and then click Open.
- You should see the newly added folder in your symbol library!

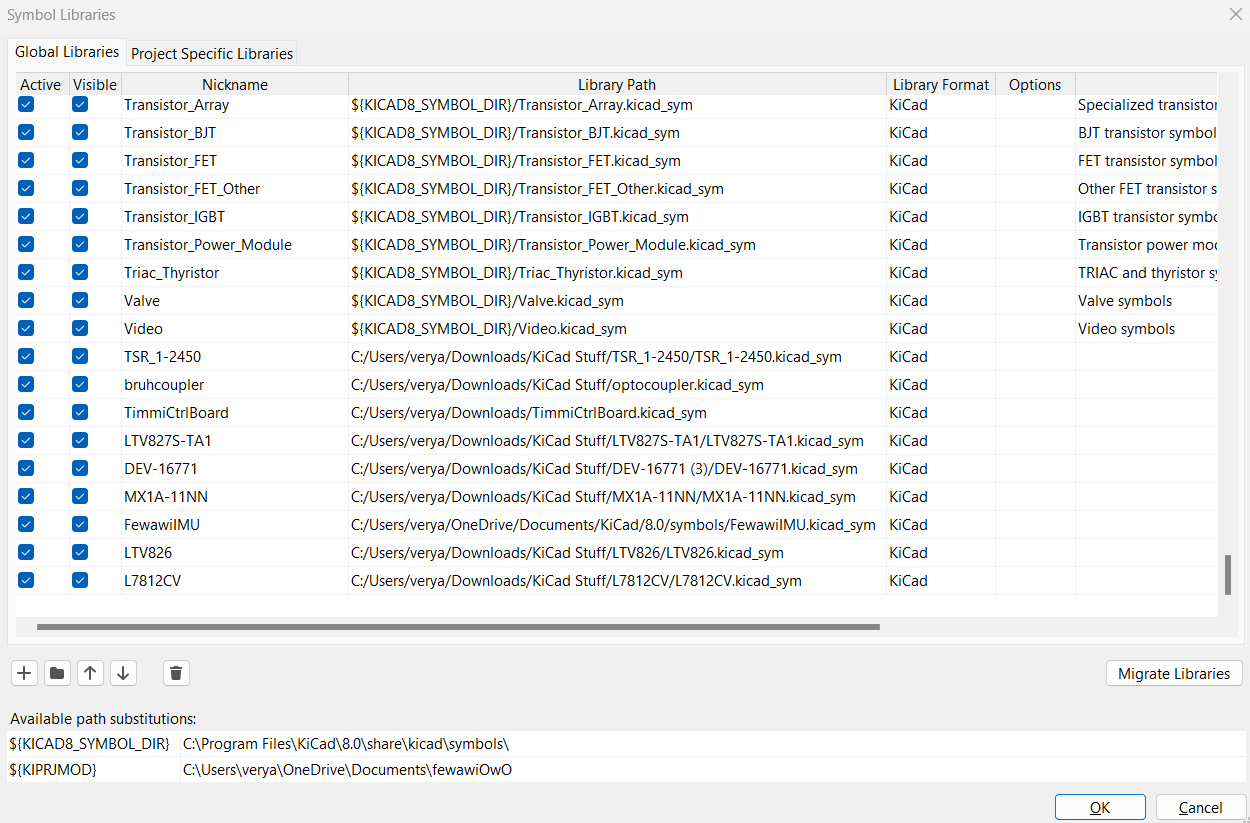
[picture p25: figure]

Figure 2: KiCAD symbol library displaying the newly added L7812CV symbol (you are not required to add this specific symbol).

### 5.1.3 Importing the Footprint into the Footprint Library

The process for this is also listed in the PDF, (https://www.snapeda.com/about/import/) but I will list the steps here again because I don’t have a life.

- In KiCAD, go to Preferences at the top left.
- Click on Manage Footprint Libraries.
- Within Global Libraries, click on the small folder near the bottom left (Add existing).
- Navigate to the folder where the .kicad mod file is located and select the folder. Note that you will not be able to see the .kicad mod file because you are supposed to select the folder that it is located in.
- You should see the newly added folder in the footprint library!

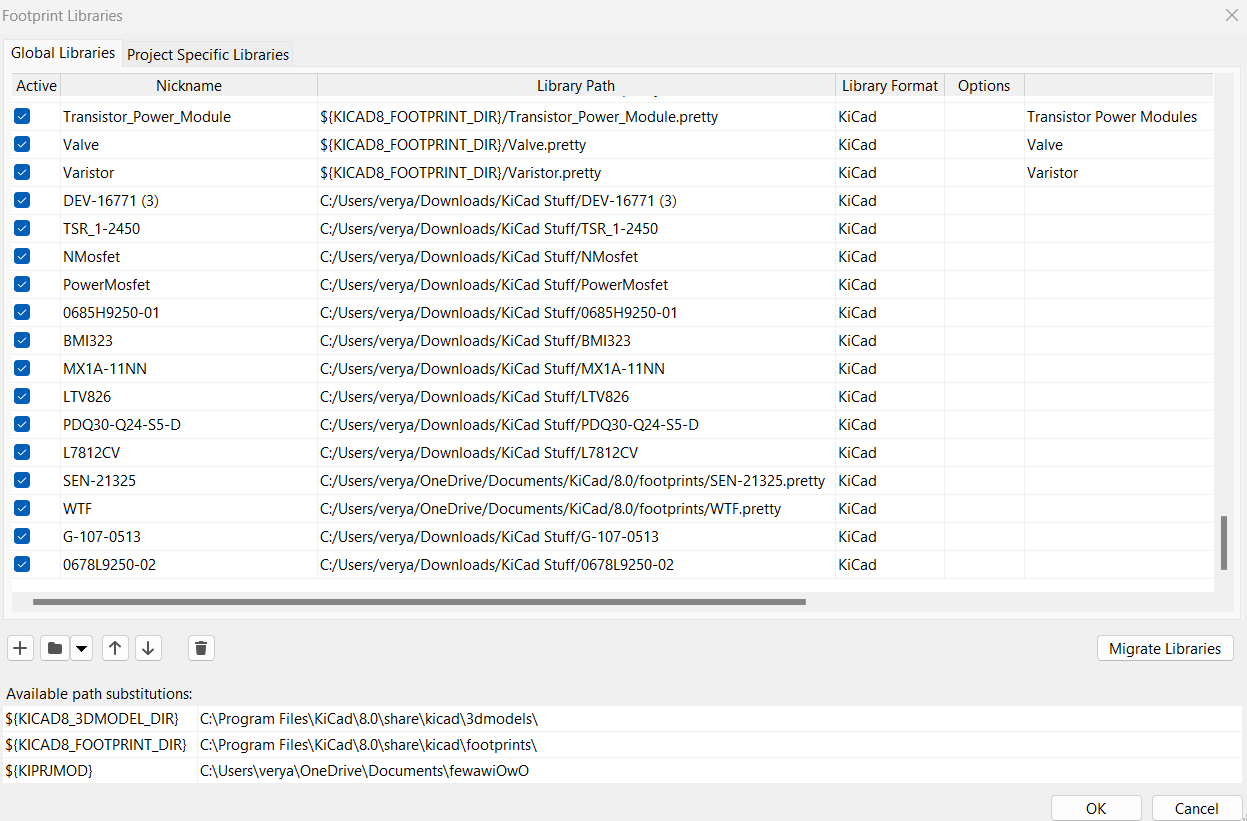
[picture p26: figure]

Figure 3: KiCAD symbol library displaying the newly added 0678L9250-02 footprint (you are not required to add this specific footprint).

### 5.2 Your turn!

- Following the steps above, do the same thing but for the rest of the parts listed above.
- Add both the symbols and the footprints of each of the parts to their respective symbol and footprint libraries.
- When you’re done, you should see those parts in their libraries. We will be using these in the next lab when making our schematic.

## 6 Making Your own Symbol or Footprint

I will not be covering how to do this yourself because it is not very beginner friendly, and it is much more efficient in your RoboJackets career to take other people’s work. However, there may be cases in which you may have to make your own symbol or footprint for a part. If you are interested in looking how to do this, here is a link to how to do so.

- KiCAD Getting Started Guide (https://docs.kicad.org/7.0/en/getting_started_in_kicad/getting_started_in_kicad.html) - Includes how to create a custom symbol and footprint for any part

## 7 Troubleshooting

For any problems with your KiCAD or GitHub Desktop/Git installations please reach out to a trainer who can help with your specific issue. Below is a powerpoint presentation I made that goes over the same concept, but more specific to RoboWrestling. For importing symbols and footprints, those will be near the beginnings of the two powerpoints listed below.

- RW Schematic Tutorial (https://docs.google.com/presentation/d/1sggm3aOZvK8xawhW5PRm9fKLOVgAQe5-AmndBls0wEk/edit?usp=sharing)
- RW PCB Tutorial (https://docs.google.com/presentation/d/1N1bRbB5CjgjS3HoQQU43WC_-M5jsURQIUxiynEX3LLE/edit?usp=sharing)

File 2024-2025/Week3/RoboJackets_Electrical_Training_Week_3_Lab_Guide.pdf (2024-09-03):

# RoboJackets Electrical Training Week 3 Lab Guide

Kyle Nguyen

August 23, 2024
v1

## Contents

1 Background | 2
2 Initial Steps | 2
3 Materials | 2
4 Relevant Information | 2
5 Guided Lab | 5
6 Troubleshooting | 11

## 1 Background

This week’s lecture topic was on designing schematics with KiCAD. A majority of RoboJackets will use KiCAD to design printed circuit boards (PCBs) for their robots. For this reason, it’s important to feel comfortable using this software and learn about the many different features KiCAD offers for PCB design. In this lab, you will be creating your own schematic from scratch. Your job is to place the required components and connect them with nets. You will need to download some parts from SnapEDA (https://snapeda.com/) as mentioned in Lab 2.

## 2 Initial Steps

### 2.1 Checking Libraries for Required Parts

The last lab required you to download some parts and put them into your KiCAD symbol and footprint libraries. Go into your symbol and footprint libraries and make sure the following parts are in there:

- Teensy 4.1 (Microcontroller) (https://www.pjrc.com/store/teensy41.html)
- Cherry MX Black Switches (MX1A-11NN) (https://www.digikey.com/en/products/detail/cherry-americas-llc/MX1A-11NN/91136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)
- Motor Driver (A4950ELJTR-T) (https://www.digikey.com/en/products/detail/allegro-microsystems/A4950ELJTR-T/2626338)
- Voltage Regulator (TSR 1-2450) (https://www.soselectronic.com/en/products/tracopower/tsr-1-2450-70570?gad_source=1)

If you did not attend last week or you do not see these parts in your libraries, please talk to an instructor.

### 2.2 Create a Project

The last lab also had you make a project. If you have not created a project yet, click on File → New Project and choose whatever project name you want. Make sure the Create a new folder for the project checkbox is ticked, then click Save. This will create your project files in a new subfolder with the same name as your project.

## 3 Materials

- Computer/Laptop
- KiCAD
- Mouse

## 4 Relevant Information

### 4.1 Adding parts to your schematic

You can click the Add a Symbol button located in the right menu of the schematic editor or press “A” to open the part selection menu.

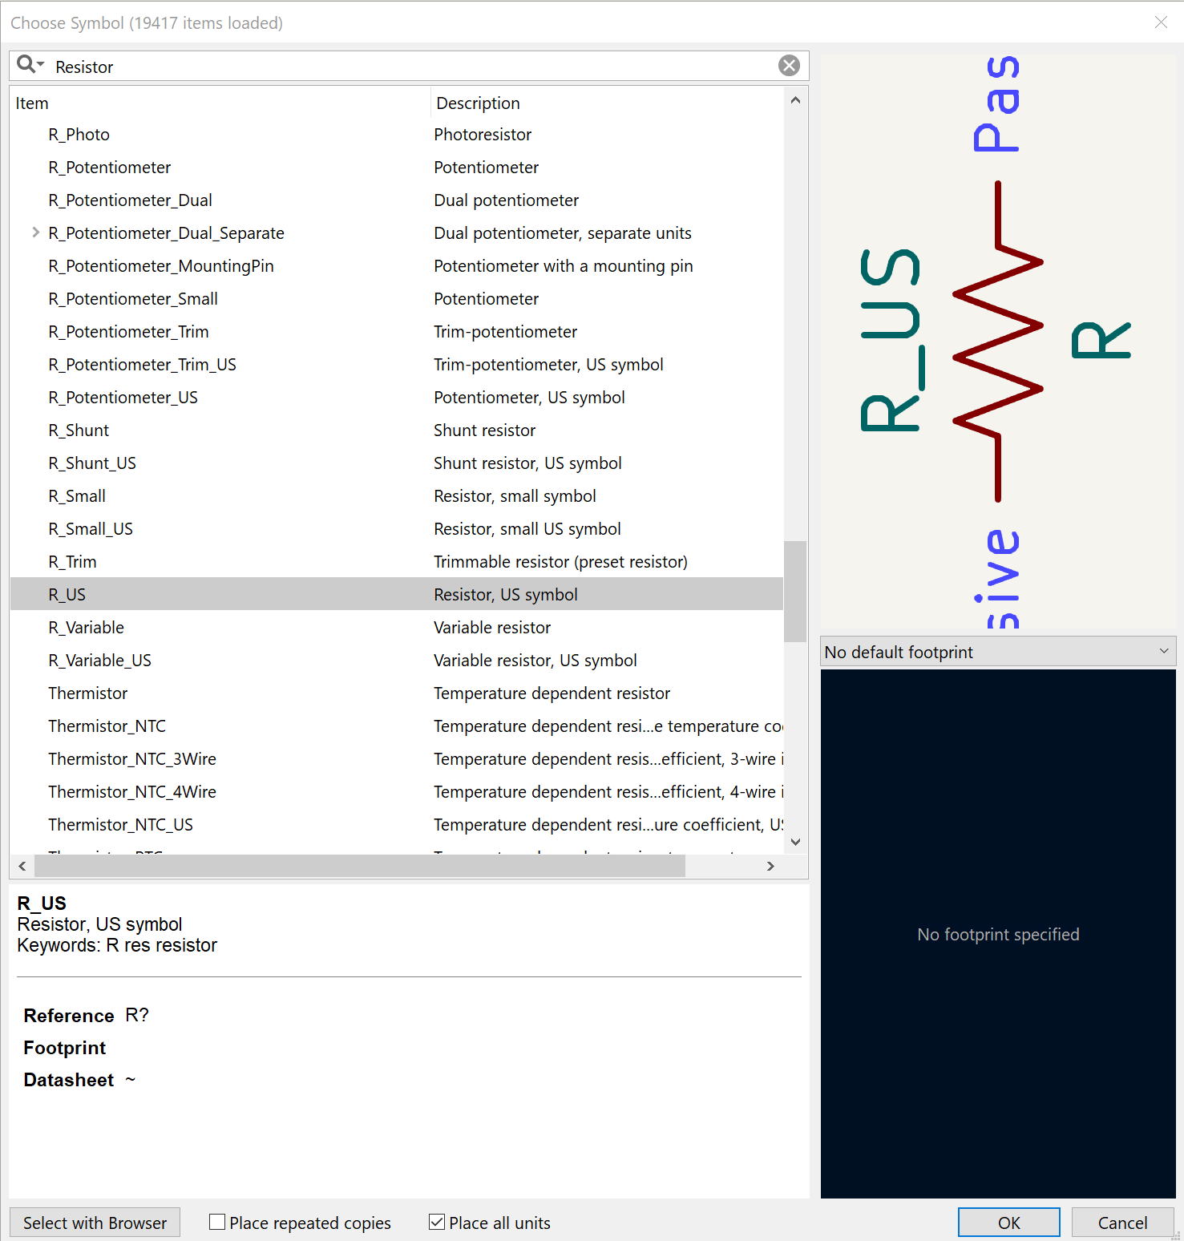
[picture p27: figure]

Figure 1: Add Symbol Menu

### 4.2 Adding global labels

If there are connections that need to be made far away from each other, you can use the “Add a global label” button in the right menu to do this.

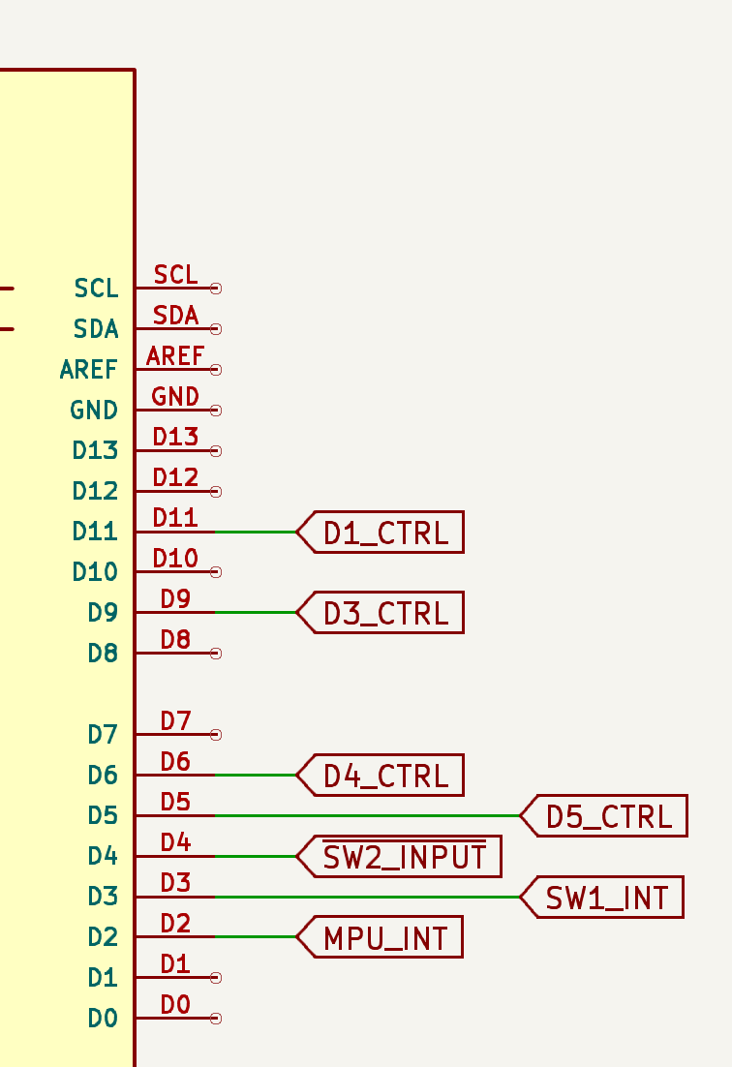
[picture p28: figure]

Figure 2: Adding labels

### 4.3 Changing your grid size

If you encounter any difficulties trying to connect pins in the schematic editor, you can press your CTRL key to get more precise placement. Alternatively, you can change your grid size. This can be done by going to View > Grid Properties and changing the size under “Current Grid”. A grid size of 2.54 mm (0.1 in) is recommended because most if not all symbols should have pins separated by 0.1”. However, if this is too large, then 0.254 mm (0.01 in) is recommended so that the grid is simply divided by 10.
You can also define your own grid size under the “User Defined Grid” section. Remember to set the current grid to User grid to actually use the custom grid size. Lastly, the Fast Switching section allows you to quickly switch between two different grid sizes which may be handy if you need to zoom in to any part of your schematic and have more gridlines (for Windows, you press Alt+1 or Alt+2 to switch to the

corresponding grid size).

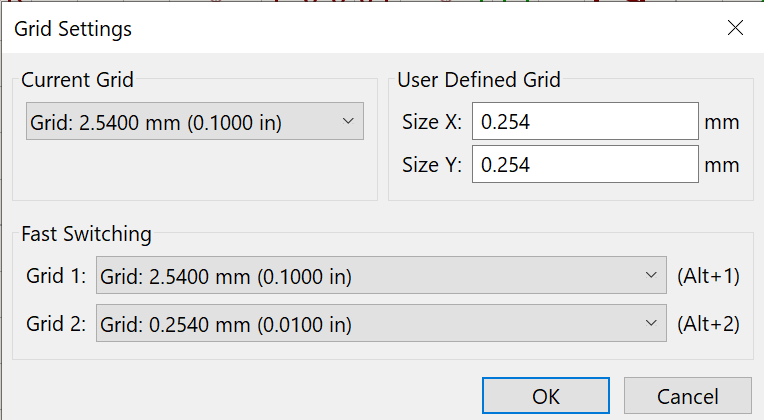
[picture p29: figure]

Figure 3: Grid Settings Menu

### 4.4 Decoupling Capacitors

Decoupling capacitors are capacitors that are normally placed between power and ground to protect the circuit parts from random spikes in voltage. These capacitors normally take values of 0.1µF, but depending on the part, it could be different. To check what value capacitor you need or the wiring configuration, check the datasheet for the part.

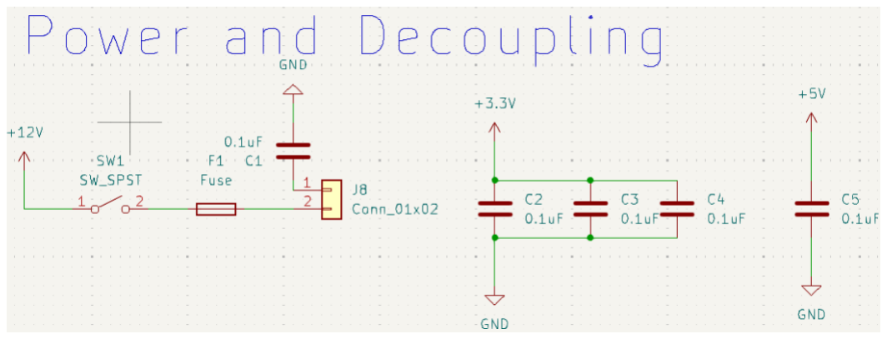
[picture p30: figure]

Figure 4: Some examples of decoupling capacitor applications in KiCAD.

## 5 Guided Lab

Open your project. Get ready to tweak! :3

### 5.1 Symbol Placement

The first step to making a schematic is placing all your parts down. When placing your parts, make sure all of your similar parts are next to each other. For bigger parts with lots of connections, try to place those farther away from the simpler parts.

### 5.1.1 Add the Microcontroller

- Select Add a symbol in the right bar and search for your microcontroller. The specifc one we wanted should be labelled something along the lines of ”DEV-16771” for the Teensy 4.1.

- Place this somewhere convenient.

### 5.1.2 Add the Motor Drivers

While writing this lab, I realized that the voltage regulator is going to take a lot of time to wire. To make your life easier, please click on this link that will redirect you to the electrical training Github.

- Download CopyAndPasteThisLab3.kicad sch inside of the Week 3 folder.
- Copy and paste this into your schematic.

### 5.1.3 Add the Mechanical Switches

- Select Add a Symbol and search for the MX1A-11NN buttons you added.
- Place 2 of these switches somewhere convenient. Again, they don’t have to be close to any of the other parts you have already placed.

### 5.1.4 Place the Voltage Regulator

- Select Add a Symbol and search for the TSR 1-2450 voltage regulator you added.
- Place this part somewhere convenient.

### 5.1.5 Place your Battery Connection

You may have noticed we did not include a battery! This is because KiCAD already has a connector symbol for what we are going to be using for this.

- Select ”Add a symbol” and type ”connector generic” into the search bar.
- Select the 1x02 size and place it somewhere convenient.

### 5.2 Organization

At this point in your schematic creation, it is a good idea to organize your parts so it is more readable. To do this, we will border off our parts to separate them and label them so we know what specific purpose they serve.

### 5.2.1 Adding Borders

- In the panel on the right, select Draw a Rectangle and draw rectangles around your similar parts.

### 5.2.2 Adding Titles

- In the panel on the right, select Add Text and add descriptions of each rectangle at the top.
- A good text size is 200 mils, but you can choose whatever value you want (as long as you can read it).

### 5.2.3 Labelling Parts

To specify which symbol corresponds to what purpose, it is good practice to label them. To do this, right click on the symbol, click on Properties, and change the Value parameter to something meaningful. The symbols you do this for is completely up to you, but for this lab you should at least:

- Change the button values to ”Button1” and ”Button2”.
- Change the motor driver values to ”MotorDriverLeft” and ”MotorDriverRight” (should already be done for you).

- Change the generic connector value to ”BatteryConnector”.

Hopefully, your schematic looks like this now:

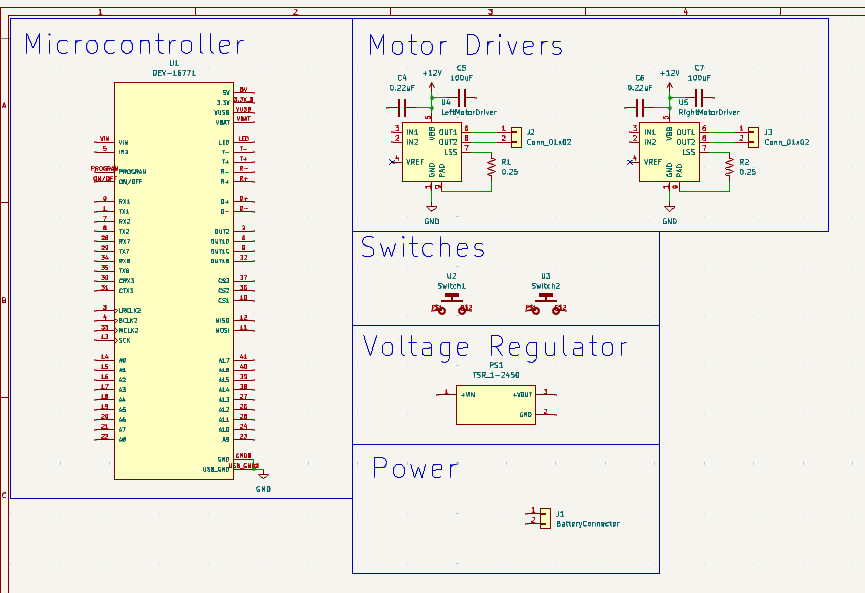
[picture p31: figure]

Figure 5: KiCAD schematic with all parts placed and organized for a specific PCB layout. Ignore the unconnected motor driver grounds.

### 5.3 Wiring

### 5.3.1 Microcontroller Wiring

- Start by wiring power to the Teensy. To do this, click on the Add Power panel on the right (or press
P) and select 5V.
- Connect this to Vin by clicking on the tiny circle on either the microcontroller or the power symbol, and connecting the wire to the corresponding pin.
- Do the same to connect the 5V output and 3.3V outputs on the Teensy.
- Do the same to connect the Teensy ground(s) to GND.
- Decouple the powers! For more information on how to do this, refer to section 4.5 on Decoupling Capacitors, or copy the image below.

Hopefully, your microcontroller looks like this now:

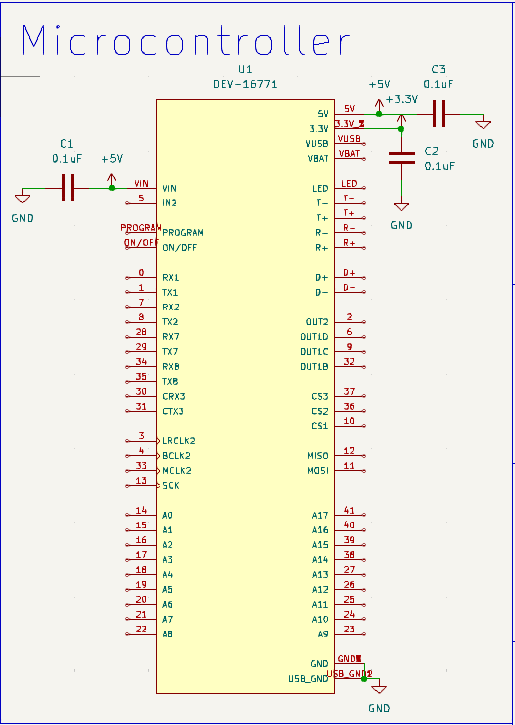
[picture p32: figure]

Figure 6: Teensy 4.1 with pins connected to power. The microcontroller is properly decoupled.

### 5.3.2 Motor Driver Wiring

I have already done the motor driver wiring. I did it by looking at the datasheet for this part. However, there are two important connections left to make, and those are the motor driver inputs, which come from the microcontroller.

- To add a global label, click on ”Add Global Label” on the right panel. Name this label ”MD Left1” and wire it to IN1 of the left motor driver.
- Wire another global label with the same name to any PWM pin on the microcontroller. Click this link (https://www.pjrc.com/teensy/card11a_rev4_web.pdf) for a picture of the Teensy 4.1 pinout.
- Repeat this process for IN2 of the left motor driver, and IN1 and IN2 of the right motor driver.

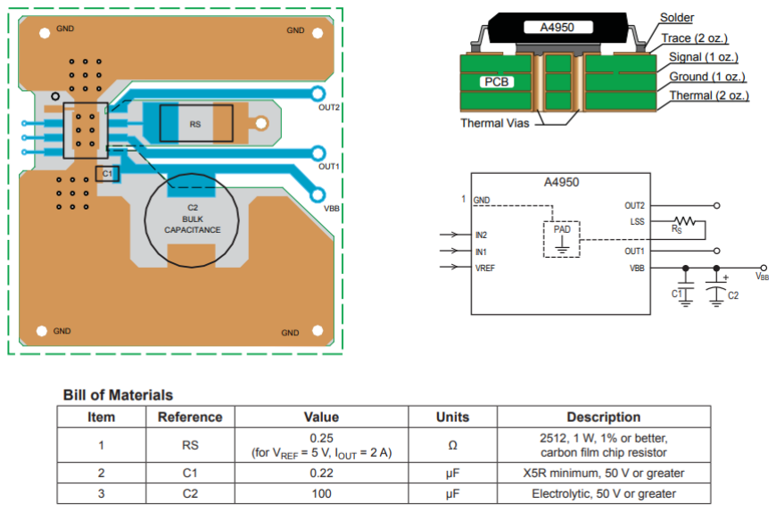
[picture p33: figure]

Figure 7: Section of the datasheet for the A4950ELJTR-T motor driver showing how to wire the component.

### 5.3.3 Wiring the Switches

Add power, resistors, and global labels to wire the switch like so:

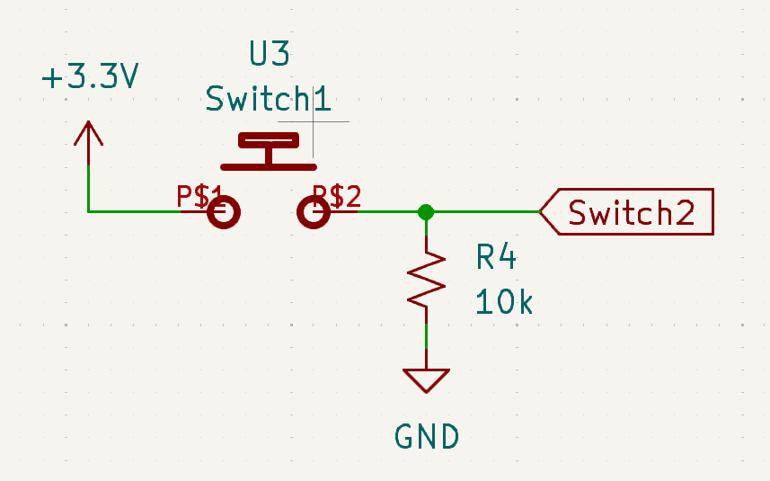
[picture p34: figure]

Figure 8: Demonstration of a pull-down resistor in a KiCAD schematic.

Some things to note:

- Power here is 3.3V because the PWM pin takes in a 3.3V signal.
- The resistor is there to guarantee that the signal is 0 (grounded) when the switch is up. This resistor is called a pull-down resistor. For more information, you can look up pull-up or pull-down resistor on

Google for many more examples.

- Attach the other end of the global label to any PWM pin on the microcontroller.

### 5.3.4 Wiring the Voltage Regulator

The voltage regulator takes in a certain range of voltages and outputs a fixed voltage. Wiring this component is fairly simple.

- Vin will be the voltage of our battery, which is 12V in this case (it depends what battery you are using). Attach 12V to the Vin pin.
- Vout will be the output voltage of the voltage regulator, which is 5V for this part. Attach 5V to the Vout pin.
- Wire ground to the GND pin.
- Decouple your powers to ground (12V and 5V).

### 5.3.5 Wiring the Battery

A battery has a positive end and a negative end. We will assume the negative end to be GND and attach each end of the connector to a terminal of the battery.

- Wire pin 1 of the connector to GND.
- Wire pin 2 of the connector to 12V.
- Add a decoupling capacitor between pin 1 and GND.

For our purposes, we will use a simple battery connector like this without any circuit protection. However, you will probably have to add a fuse and a switch to your battery connections to protect your components from getting fried. For more information on this, check out the RW Schematic Tutorial Slides that I made in the Troubleshooting section.

### 5.4 Placing No Connect Flags

- For your unconnected Teensy pins, place No Connect Flags on them. The icon is on the right, and it looks like an X.

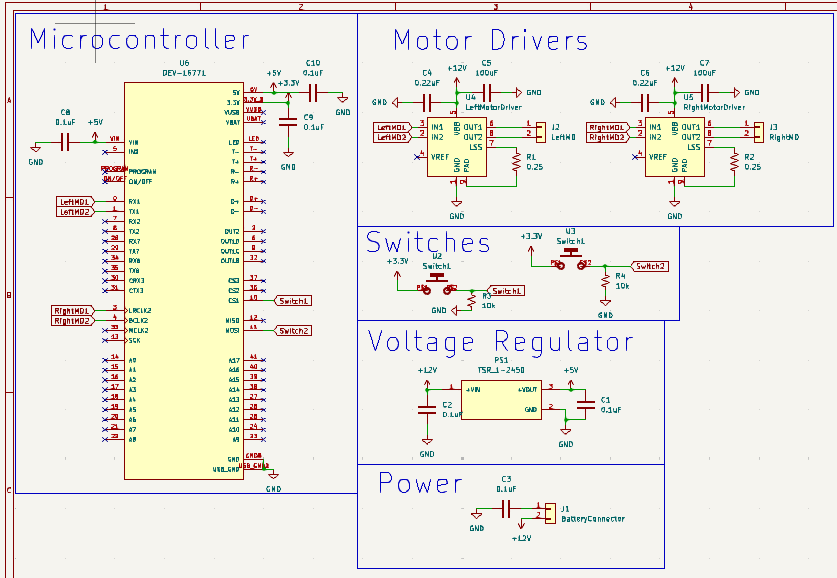
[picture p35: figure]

Figure 9: Final KiCAD schematic of a specific PCB.

### 5.5 Running Electrical Rules Checker

To check if there are any issues with your schematic, run the Electrical Rules Checker (ERC) by clicking on the checklist icon in the top bar. It’s recommended to run ERC while your grid size is on 0.1 in to ensure all of the wires and parts are spaced appropriately.

## 6 Troubleshooting

If you have any questions or concerns, please ask your instructor. Most ERC errors can be fixed quickly with a simple Google search. Here are some additional resources if you need help.

- KiCAD Getting Started Guide (https://docs.kicad.org/7.0/en/getting_started_in_kicad/getting_started_in_kicad.html) - Includes how to use the schematic editor
- RW Schematic Tutorial (https://docs.google.com/presentation/d/1sggm3aOZvK8xawhW5PRm9fKLOVgAQe5-AmndBls0wEk/edit?usp=sharing)

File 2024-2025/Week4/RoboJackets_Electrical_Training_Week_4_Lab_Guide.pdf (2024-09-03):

# RoboJackets Electrical Training Week 4 Lab Guide

Kyle Nguyen

September 3, 2024
v1.0

## Contents

1 Background | 2
2 Objective | 2
3 Relevant Information | 2
4 Guided Lab | 4
5 Troubleshooting | 9

## 1 Background

This week, we are addressing how to create the Board Layout design of a PCB. There are many specific details to the art of designing a PCB, but our main intention is to introduce you to the basics of it all. Every time that you want to make a PCB for attending your specific application, you need to go through some steps and that’s not different in RoboJackets. Every team has several different boards that support either their main robots or parallel projects that are relevant for the team. On this lab, we will design the PCB Layout of the Firmware Training Board. This is the same board which you all have made the schematic last week.

## 2 Objective

### 2.1 Board dimensions

The board size depends a lot on the application and on the constraints set by the components that will go on the board. For example, smaller boards are preferable if you want to put your board inside a tight system like a robot (and in most cases actually), however if the end-application don’t have many physical constraints, you can make your board bigger and thus make it easier to routing traces on it and soldering the components after the PCB is manufactured.

### 2.2 Optimize User Experience

In the end, you want your board to look good and to be informative enough for the end-user.

### 2.2.1 Silkscreen

Use the Silkscreen layers to put information for people assembling or using your board. In general, people tend to put less information than it would be helpful, however, don’t put too much unnecessary silkscreen to a point of polluting the board view. You can also put graphics and silly messages to people on the silkscreen (sorry Jinhee, but you need to get out of bed).

### 2.2.2 Space between components

Especially if your board is going to be soldered, remember to put some space between components so that if it needs to be assembled or debugged, the user can easily take out or put components.

## 3 Relevant Information

### 3.1 Datasheet!

You thought that you only would need to analyze datasheets while doing the schematics and choosing the components for your board? Nope! The datasheet has very useful information on how to do the layout. It will suggest the positioning of certain supportive discrete components (like resistors and capacitors) and how should the polygons and traces around the main component look like. In fact, it will commonly show you an example of a working Board Layout like in Figure 1.

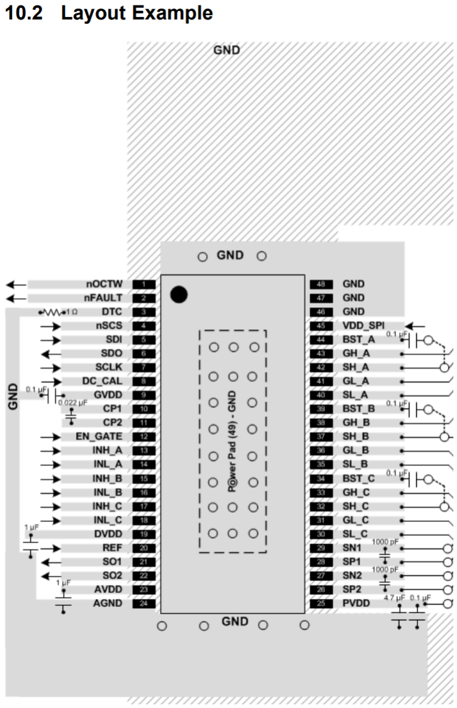
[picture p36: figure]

Figure 1: Layout example from a component’s (DRV8303) datasheet. Note it suggests the positing of capacitors and the width of certain traces.

### 3.2 Terminology

Here are some terms you should be comfortable with:

- Layers: Different categories for elements in the board. The KiCAD PCB editor documentation has some details on some of the important KiCad layers: https://docs.kicad.org/7.0/en/pcbnew/pcbnew.html (https://docs.kicad.org/7.0/en/pcbnew/pcbnew.html)
- Trace: The filament of copper that connects pins around your board.

- Via: Copper platted hole that goes from top to bottom layers and passes by all the other layers.
- Polygon: Region of board designated to be entirely filled with copper and thus can be used to connect pins.

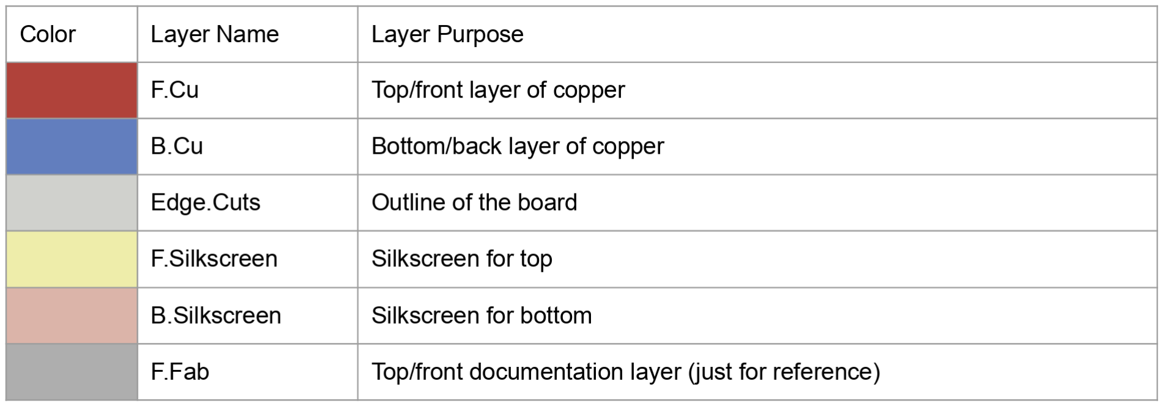
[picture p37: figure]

Figure 2: Quick explanation of layers you’re most likely to use.

### 3.3 Ground Layer

The ground plane is a conductive layer in the PCB that acts as a common ground reference point for electrical signals and currents. The ground plane is used to minimize electromagnetic interference, provide a return path for the signals, and dissipate heat in high-power applications. From a beginner standpoint, just know that you should use a ground layer to connect all of your grounds.

## 4 Guided Lab

### 4.1 Setup

Open the KiCAD schematic from the last lab. If you were unable to come to the last lab(s), download the ElectricalTrainingLab.kicad sch file in the Week 3 folder in the electrical-training repository in Github for you to download. Copy and paste the contents of the schematic file into your own project. If you don’t have a project open because you don’t like seeing me during these electrical training meetings, make one by going to File at the top left and clicking New Project.
Open your footprint library and make sure the following footprints are in the library:
- Teensy 4.1 (Microcontroller) (https://www.pjrc.com/store/teensy41.html)
- Cherry MX Black Switches (MX1A-11NN) (https://www.digikey.com/en/products/detail/cherry-americas-llc/MX1A-11NN/91136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)
- Motor Driver (A4950ELJTR-T) (https://www.digikey.com/en/products/detail/allegro-microsystems/A4950ELJTR-T/2626338)
- Voltage Regulator (TSR 1-2450) (https://www.soselectronic.com/en/products/tracopower/tsr-1-2450-70570?gad_source=1)

If the any of these are not in your footprint library, please talk to an instructor.

### 4.2 Assign Footprints

- With your schematic open, go to Tools ¿ Assign Footprints.
- There may be footprints already assigned to certain symbols, but delete those for now. We want to make sure that the footprint that we want is the one we actually want (just click on it and hit delete).
- In the search bar, type in 0805 capacitor hand solder and select the option that pops up. Assign this footprint for all of the capacitors in the list. 0805 is the size of the capacitor. For more information on these types of footprints, click on this link. (https://i.ebayimg.com/images/g/a9YAAOSwKGxfu9c1/s-l1200.webp)
- In the search bar, type in 805 resistor hand solder and assign this footprint to all of our resistors.
- For the battery connector, search XT60 1x02 Vertical and assign the female option to this symbol.
- For LeftMDConn and RightMDConn, search Conn Phoenix 1x02 5.00mm and select the horizontal version without the threaded flanges.
- For the rest of the parts, search up the footprint names and assign them to their respective symbols.

Your footprint assignment screen should look something like this now:

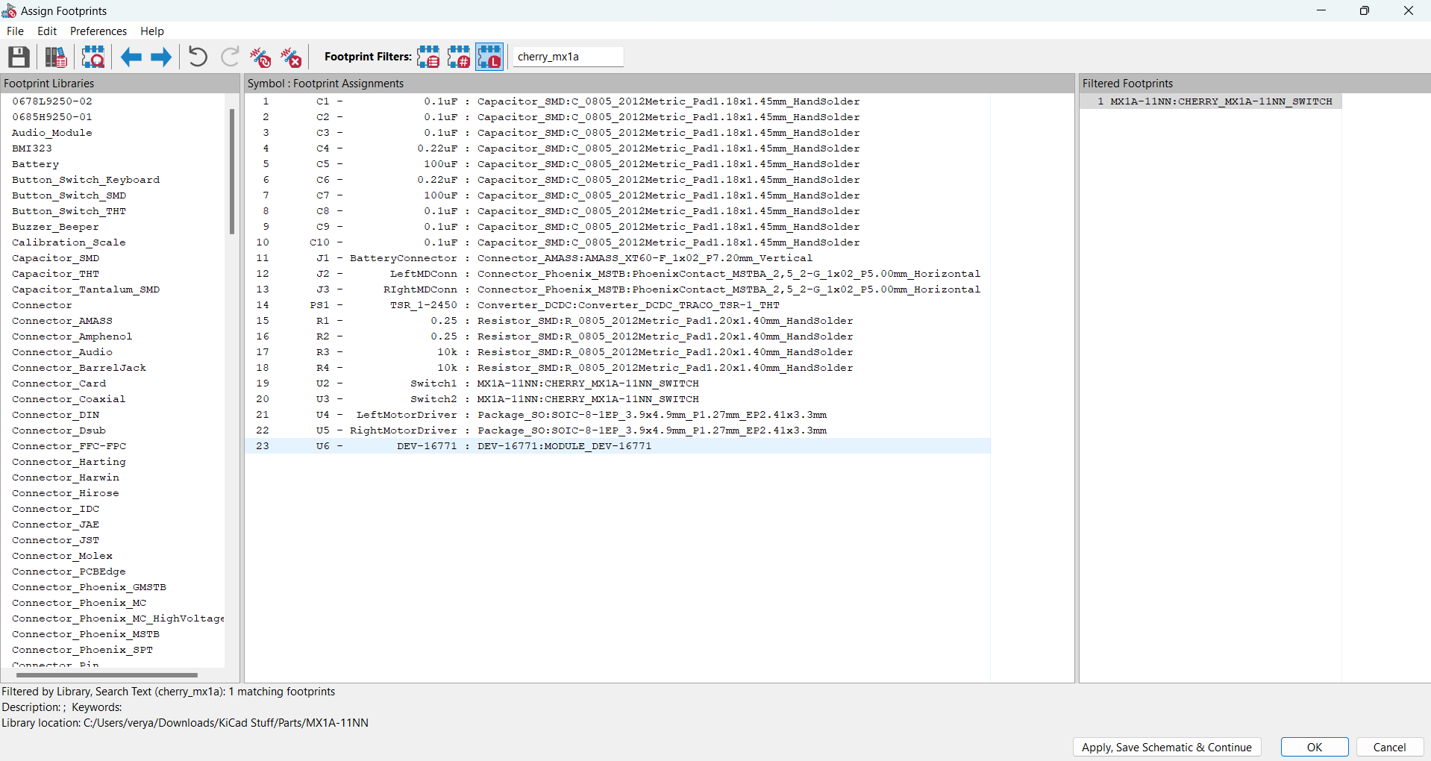
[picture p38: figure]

Figure 3: Footprint assignment in KiCAD with all parts filled out for a specific PCB.

### 4.3 Update PCB from Schematic

- In your schematic window, go to Tools at the top and then click Update PCB from Schematic.
- You will be redirected to the PCB Editor window. Click Update PCB and all of your footprints should appear.

### 4.4 Setting the PCB Bounds

- Select Edge Cuts in the right panel under Layers.
- Select Draw Rectangle from the panel on the right side (not under Layers).
- Make a 72mm x 70mm border. Normally, you would check with your mechanical member about the size of your PCB, but since I’m your instructor, you will make it 72x70 mm.

### 4.5 Footprint Placement

Footprint placement is purely subjective. As the designer, you are allowed to place parts wherever you want. However, here are some suggestions:

- Place the Teensy so that the USB side is close to the edge of the board so it’s easy to plug stuff into it.
- Keep the right motor driver components on the right side, and keep the left motor driver components on the left side.
- Keep related parts next to each other. For example, if a specific resistor belongs with a switch, keep those two footprints close together.

Here is an example of how you could place the footprints:

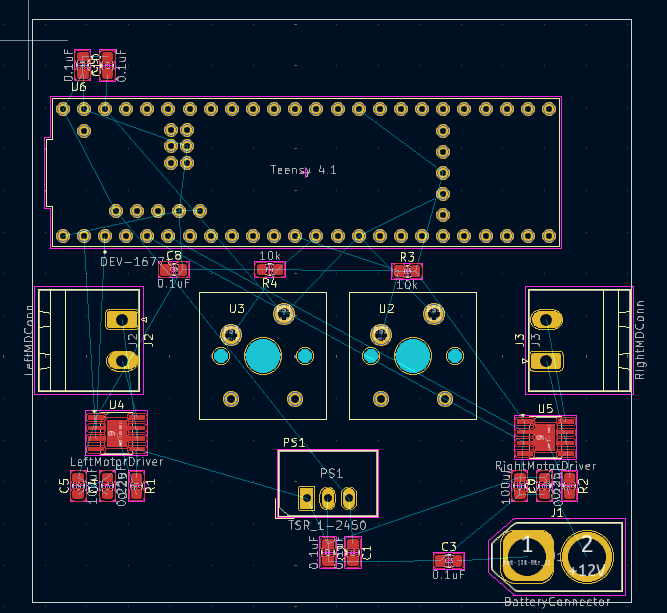
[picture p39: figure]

Figure 4: A possible layout for a specific PCB in KiCAD. Please note that there could be a better way to do this.

### 4.6 Wiring

- DO NOT WIRE GROUND. We will take care of that later.
- Press X on a pad to start drawing a wire. The blue lines indicate where you need to connect that wire to.
- If you find yourself trying to cross another wire, press V to place a via. The wire should change colors (either from red to blue or blue to red, depending on what layer you were on before) and you should be able to cross that wire.
- Wire everything that you need to until you have only grounds left.
- You may need to rotate or move some parts so wiring is easier.
- You may also need to change pin assignments on your Teensy if you want to make wiring easier.

### 4.7 Ground Layer

- To place the ground layer, select F.Cu in the Layers menu on the right, and then click Add Filled Zone in the panel on the right (not under Layers tab).
- Click on a corner of your PCB, and a menu should pop up.
- Under Layer, select both F.Cu and B.Cu. Under Net, select GND. Click OK to continue.
- Click the rest of your PCB corners to create the borders for the ground layer.
- Click B to fill in the zone.

Your PCB should look similar to this now:

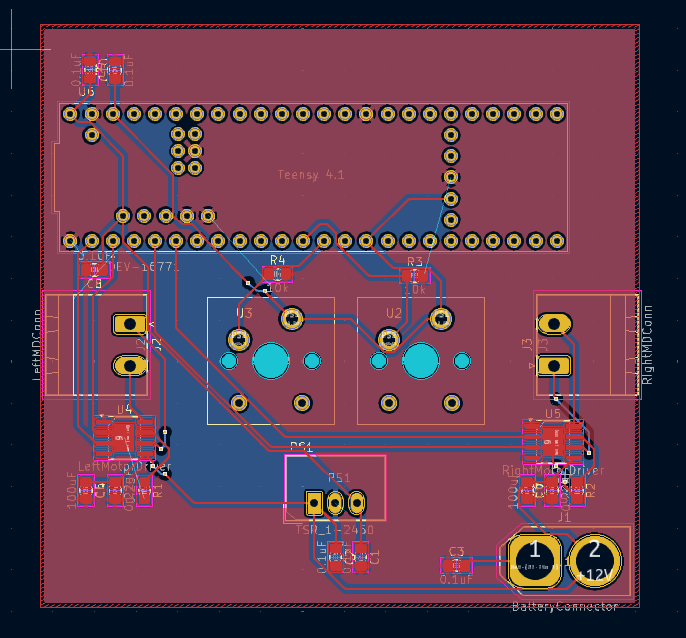
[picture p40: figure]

Figure 5: A complete wiring for a specific PCB in KiCAD. Note that the wiring and placement does not have to be the same as this; in fact the wiring could have been done much more efficiently if I wasn’t lazy.

## 5 Troubleshooting

To make sure that your board layout design abides by the Design Rules that you have established in the beginning of this guide, press the DRC tool (looks like a checklist) in the top bar and a screen should appear. After you click Run DRC, it should describe the infractions you have committed. Thus, you can press on the errors and warnings and the screen will take you to them. You can ignore some errors, but some you cannot. If you are unsure about an error, ask your instructor.
If you are struggling, here are some resources that may help you.
- KiCAD Getting Started Guide (https://docs.kicad.org/7.0/en/getting_started_in_kicad/getting_started_in_kicad.html) - Includes how to use the schematic editor
- Git Guide (https://github.com/RoboJackets/robocup-firmware/blob/master/doc/Git.md)
- RW PCB Tutorial (https://docs.google.com/presentation/d/1N1bRbB5CjgjS3HoQQU43WC_-M5jsURQIUxiynEX3LLE/edit?usp=sharing)

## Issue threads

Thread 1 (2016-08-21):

Resize board to fit on 10cm x 10cm

petersonev, 2016-08-21:
Slightly resize board to fit 9 copies of board on a 10cm x 10cm which will be ordered from dirty pcb. Resize to approximately 3cm x 3cm

Closed 2016-08-25.

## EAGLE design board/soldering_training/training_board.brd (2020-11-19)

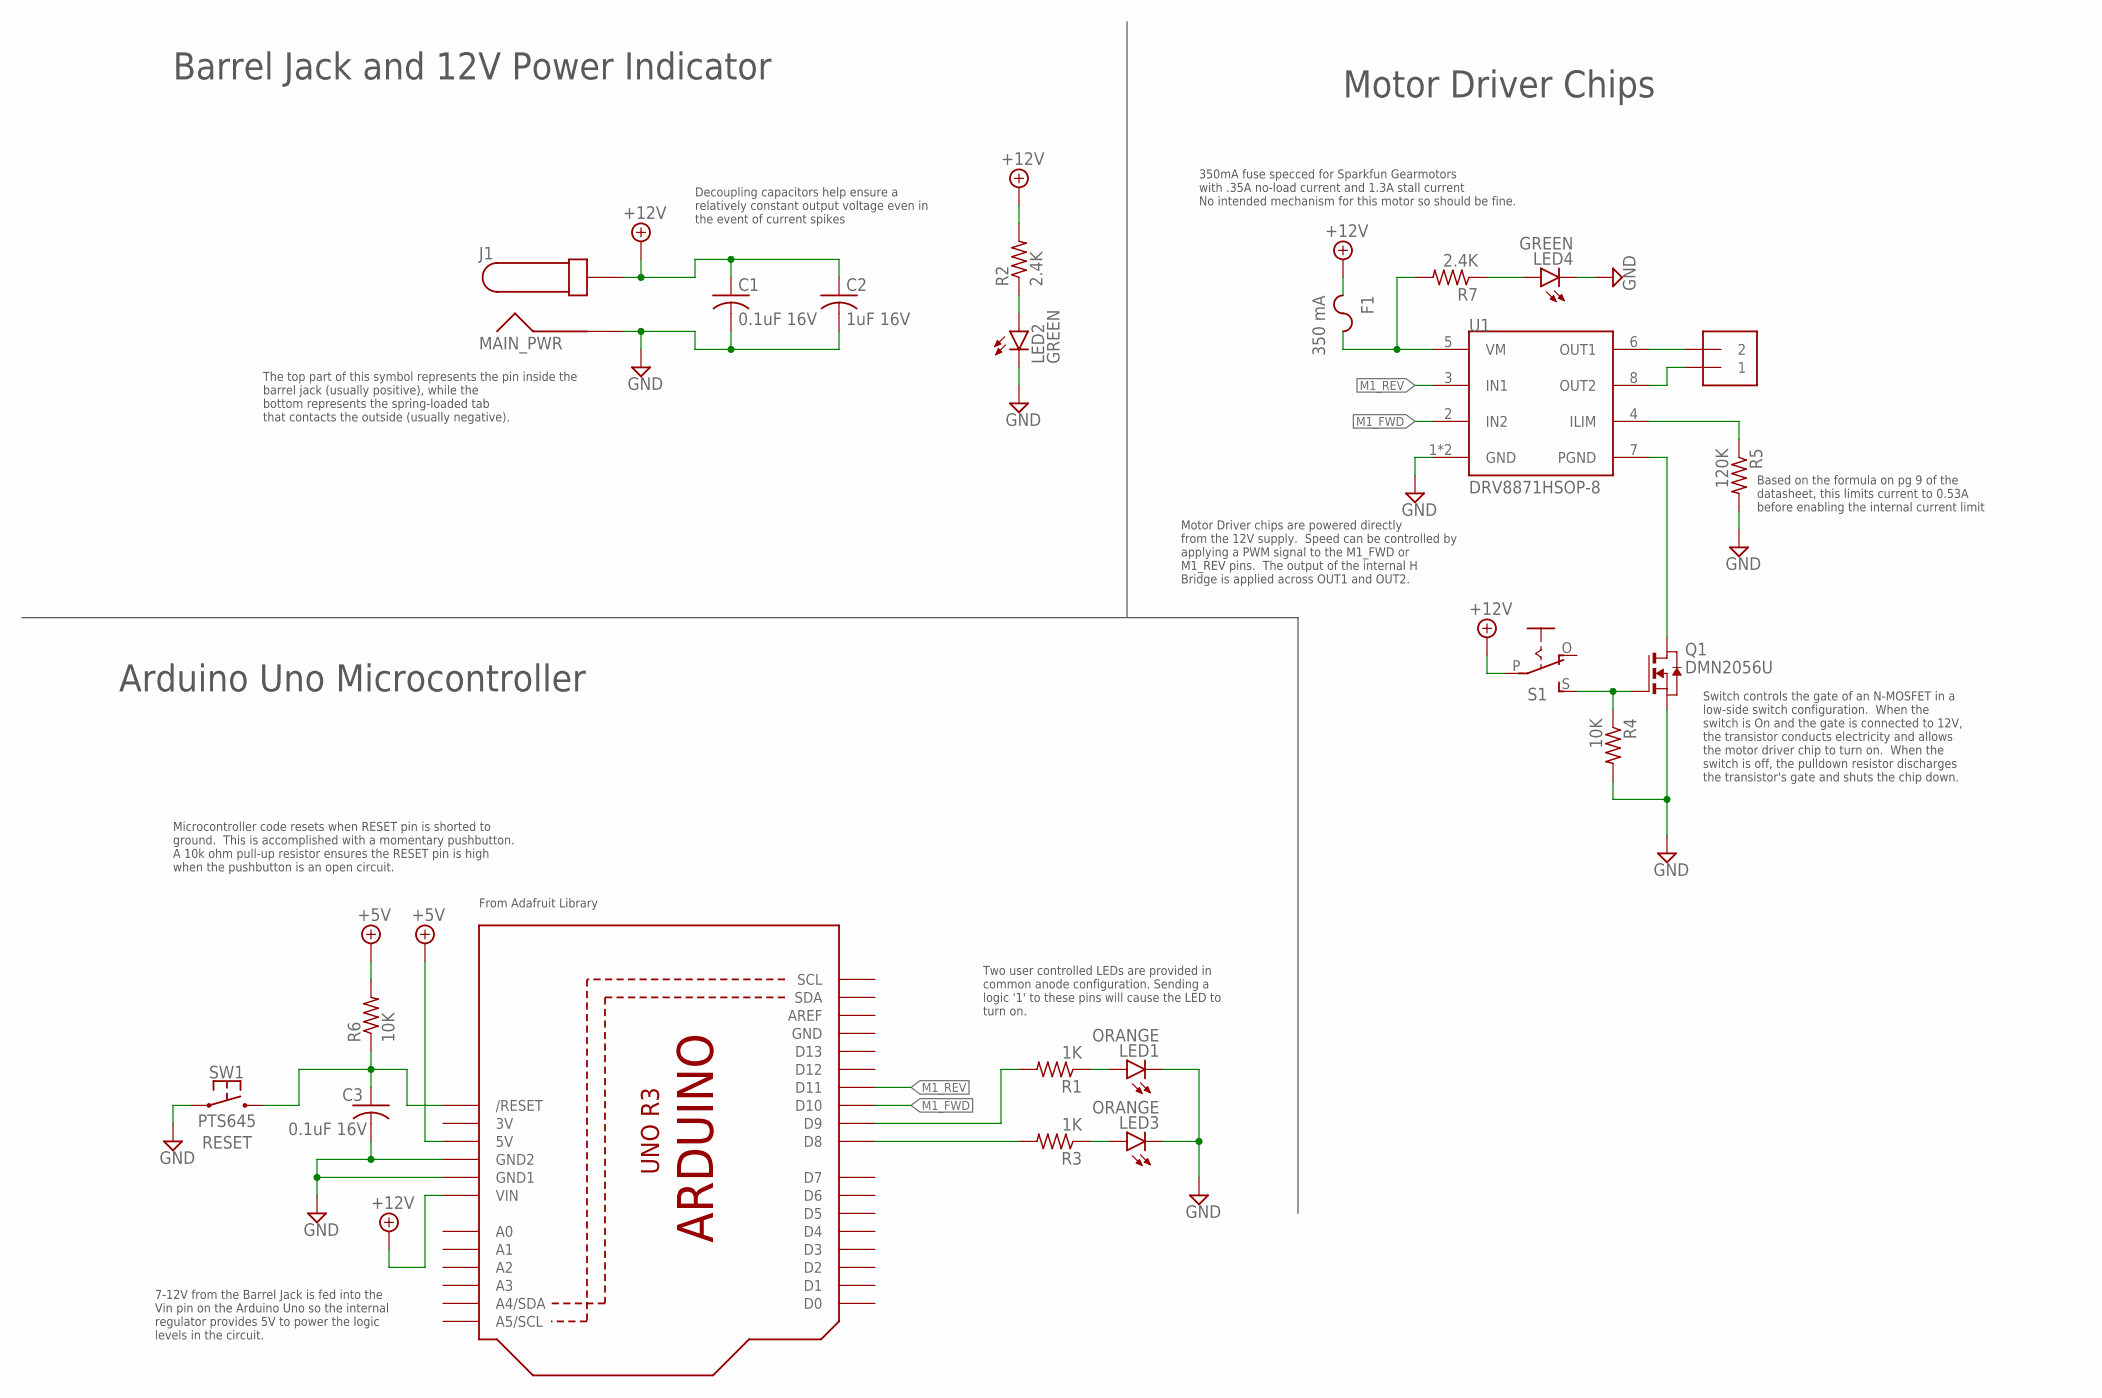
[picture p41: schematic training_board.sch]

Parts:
C1, C3: 0.1uF 16V; C0805
C2: 1uF 16V; C0805
F1: 350 mA; F1812
J1: MAIN_PWR; PJ-037A
LED1, LED3: ORANGE; CHIP-LED0603
LED2, LED4: GREEN; CHIP-LED0603
OUT: 1X2-3.5MM
Q1: DMN2056U; SOT-23-3
Q2: ARDUINOR3-NOIOREF-NOTEXT; ARDUINOR3-NOTEXT-NOIOREF
R1, R3: 1K; R0603
R2, R7: 2.4K; R0603
R4, R6: 10K; R0603
R5: 120K; R0603
S1: EG1903-ND; EG1218
SW1: PTS645
U1: DRV8871HSOP-8; HSOP-8

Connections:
3V: Q2.3V
+5V: Q2.5V, R6.2
+12V: C1.1, C2.1, F1.1, J1.P$2 (1), Q2.VIN, R2.2, S1.P
GND: C1.2, C2.2, C3.2, J1.P$1 (2), LED1.C, LED2.C, LED3.C, LED4.C, Q1.2 (S), Q2.GND, Q2.GND1, Q2.GND2, R4.2, R5.2, SW1.1, SW1.2 (1), U1.1 (GND), U1.9 (GND)
M1_FWD: Q2.D10, U1.2 (IN2)
M1_REV: Q2.D11, U1.3 (IN1)
unnamed: F1.2, R7.2, U1.5 (VM)
unnamed: OUT.2, U1.6 (OUT1)
unnamed: Q1.3 (D), U1.7 (PGND)
unnamed: OUT.1, U1.8 (OUT2)
unnamed: Q1.1 (G), R4.1, S1.S
unnamed: R5.1, U1.4 (ILIM)
unnamed: LED4.A, R7.1
unnamed: Q2.D9, R1.2
unnamed: Q2.D8, R3.2
unnamed: LED1.A, R1.1
unnamed: LED3.A, R3.1
unnamed: LED2.A, R2.1
RESET: C3.1, Q2.RESET (/RESET), R6.1, SW1.3 (2), SW1.4 (2)

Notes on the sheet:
From Adafruit Library
Barrel Jack and 12V Power Indicator
Arduino Uno Microcontroller
Motor Driver Chips
Microcontroller code resets when RESET pin is shorted to ground. This is accomplished with a momentary pushbutton. A 10k ohm pull-up resistor ensures the RESET pin is high when the pushbutton is an open circuit.
7-12V from the Barrel Jack is fed into the Vin pin on the Arduino Uno so the internal regulator provides 5V to power the logic levels in the circuit.
Two user controlled LEDs are provided in common anode configuration. Sending a logic '1' to these pins will cause the LED to turn on.
Motor Driver chips are powered directly from the 12V supply. Speed can be controlled by applying a PWM signal to the M1_FWD or M1_REV pins. The output of the internal H Bridge is applied across OUT1 and OUT2.
350mA fuse specced for Sparkfun Gearmotors with .35A no-load current and 1.3A stall current No intended mechanism for this motor so should be fine.
The top part of this symbol represents the pin inside the barrel jack (usually positive), while the bottom represents the spring-loaded tab that contacts the outside (usually negative).
Decoupling capacitors help ensure a relatively constant output voltage even in the event of current spikes
Switch controls the gate of an N-MOSFET in a low-side switch configuration. When the switch is On and the gate is connected to 12V, the transistor conducts electricity and allows the motor driver chip to turn on. When the switch is off, the pulldown resistor discharges the transistor's gate and shu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
Based on the formula on pg 9 of the datasheet, this limits current to 0.53A before enabling the internal current limit

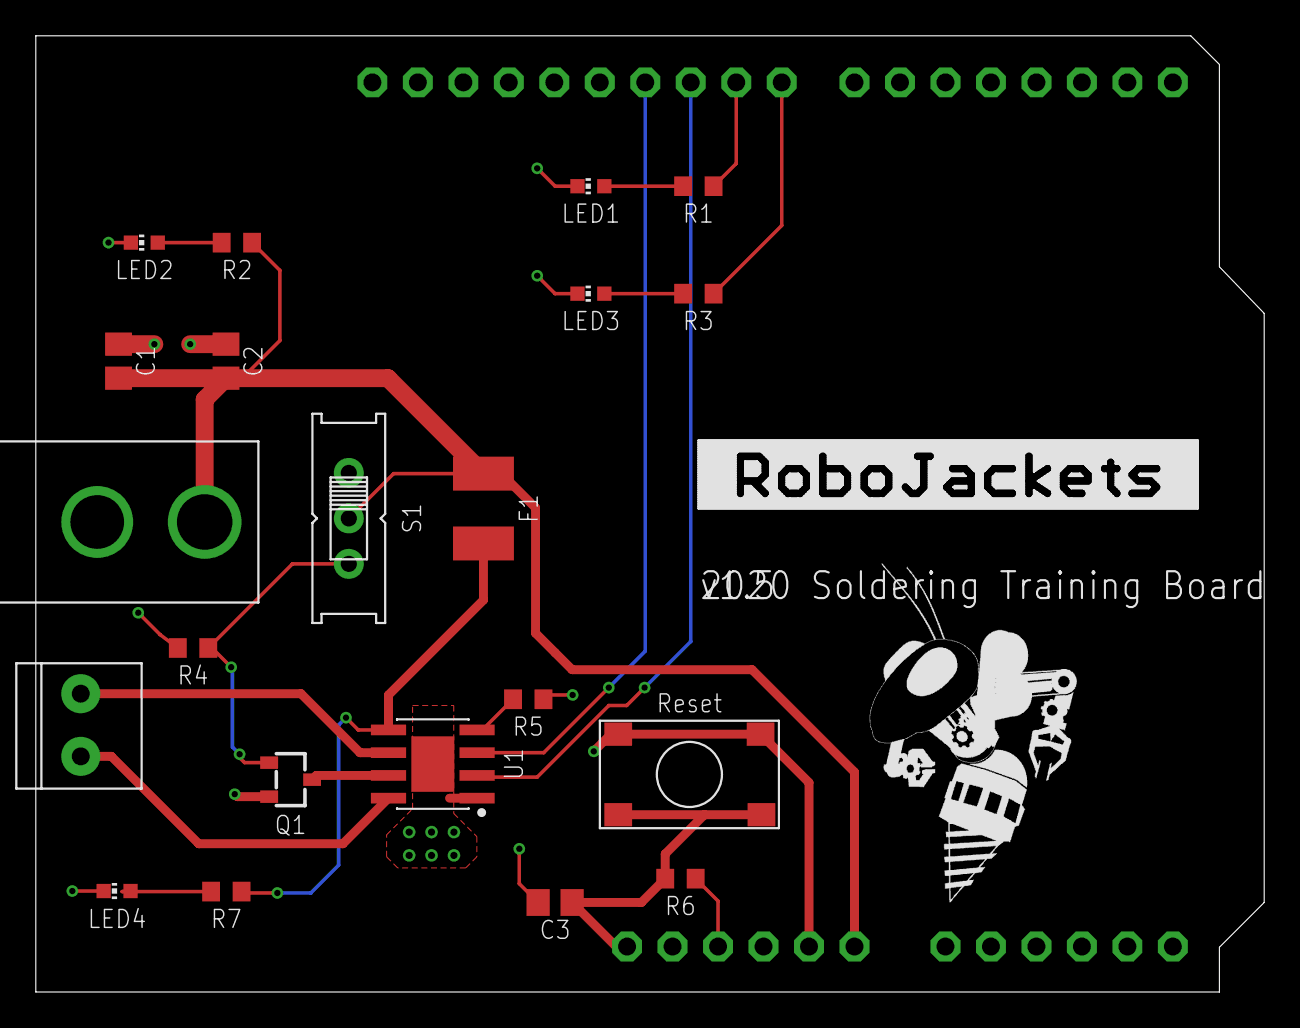
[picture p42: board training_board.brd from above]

Board: 2 copper layers, 68.6 x 53.4 mm, 24 parts (0 on the bottom side), 18 nets.

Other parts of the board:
U$1: ROBOJACKETS
U$2: ROBOBUZZ_1.0X

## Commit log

2016-08-19 Initial commit from past repository
    [rgb-led.brd, rgb-led.sch]
2016-08-19 New voltage regulator, route board, condense libraries
    [rgb-led.brd, rgb-led.sch]
2016-08-19 Fix routing error
    [rgb-led.brd]
2016-08-21 Switched RGB LED driver ICs, added button, NEEDS ROUTING
    [rgb-led.brd, rgb-led.sch]
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2016-08-23 Fixed via overlap
    [rgb-led.brd]
2016-08-25 PCB fixes for overlaps
    [rgb-led.brd, rgb-led.sch]
2016-08-25 Resize board to 30x30 then reroute
    [rgb-led.brd]
2016-08-25 Clean up routing, fix silkscreen labels
    [rgb-led.brd, rgb-led.sch]
2016-08-26 Added pullup on reset pin
    [rgb-led.brd, rgb-led.sch]
2016-08-26 Minor PCB changes, change resistor sizes
    [rgb-led.brd, rgb-led.sch]
2016-08-26 Minor pcb routing changes
    [rgb-led.brd]
2016-08-26 Fix library files
    [rgb-led.brd, rgb-led.sch]
2016-08-31 Adding Reference Design
    Same 3mm x 3mm board size
    All components on top layer
    [rgb-led_alt.brd, rgb-led_alt.sch]
2016-08-31 Eliminated Redundant Pull-Up Resistor
    The 10k on the +5V of the switch was redundant with the 39k series
    resistor already being present
    The 10k resistor has been removed
    The 39k was not value critical, so the value has been changed to 10k to
    reduce part count
    [rgb-led_alt.brd, rgb-led_alt.sch]
2016-08-31 Removed the Series Resistor Instead
    Pull-Up was OK
    The 0.1uF capacitor should be sufficient to remove switch bounce
    All silkscreen has been moved to the top layer
    [rgb-led_alt.brd, rgb-led_alt.sch]
2016-08-31 Optimized a Few Traces
    [rgb-led_alt.brd]
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2016-09-15 began arduino code directory
    [rgb-led.brd, rgb-led.sch]
2016-09-16 Fixed RGB LED Footprint
    [rgb-led_alt.brd, rgb-led_alt.sch]
2016-09-16 Got rid of a sharp corner
    [rgb-led_alt.brd]
2016-09-16 Training board minor fixes for RGB led
    [rgb-led_alt.brd, rgb-led_alt.sch]
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2017-07-29 2017-2018 Training Board initial commit
    Schematics without LCD, Buzzer and Trimmer Potentiometer
    [lcd-buzzer.brd, lcd-buzzer.sch, rgb-led.brd]
2017-07-31 First Version Completed
    Added extra custom parts to the library, completed the schematics
    [lcd-buzzer.brd, lcd-buzzer.sch]
2017-08-01 Separate clocks for registers
    [lcd-buzzer.brd, lcd-buzzer.sch]
2017-08-04 Minor Changes based on Manipulation w/ LCD
    [lcd-buzzer.sch]
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2017-08-13 Board File Initial Commit
    Library Updated. 328p pin configuration reassigned
    [lcd-buzzer.brd, lcd-buzzer.sch]
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2017-08-16 begin 3 button board
    [lec-buzzer_alt.brd, lec-buzzer_alt.sch]
2017-08-23 3 Button Board completed
    LCD flipped, slight changes in shifter, Buzzer and SPI location
    [lec-buzzer_alt.brd, lec-buzzer_alt.sch]
2017-08-23 Adds up!
    Button Number changed, Parts Added
    [lec-buzzer_alt.brd, lec-buzzer_alt.sch]
2017-08-24 Minor Updates
    Board rearranged to fit in MINI USB port. MINI USB port used as plenty
    of supply exists in the shop
    [lec-buzzer_alt.brd, lec-buzzer_alt.sch]
2017-09-02 Board Updated according to Design Review
    [lec-buzzer_alt.brd, lec-buzzer_alt.sch]
2017-09-07 Board Revision
    Reference Designator updated, wonky silkscreen fixed, Library updated
    and 2x3 header replaced with shrouded version
    [lec-buzzer_alt.brd, lec-buzzer_alt.sch]
2017-09-08 Keep updating
    Changed to Class5, schematics alignment corrected.
    [lec-buzzer_alt.brd, lec-buzzer_alt.sch]
2017-09-08 Some final glitches
    [lec-buzzer_alt.brd]
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2017-10-03 training board ver 1.5
    [lec-buzzer_alt.brd, lec-buzzer_alt.sch]
2017-10-08 2nd Version
    Indicator LED added, ATMega328p package updated, schematics updated.
    [lec-buzzer_alt.brd, lec-buzzer_alt.sch]
2017-10-08 LCD Column pin grounded
    [lec-buzzer_alt.brd, lec-buzzer_alt.sch]
2017-10-11 Training Board Updated
    A list of changes:
    1. LCD COM pin: Now connected to Arduino Pin 13
    2. ^that also means the trimmer resistor is removed
    3. LED added, connected to Arduino Pin 12, can be the first thing for trainees to play with
    4. LCD_Reset connected to A3
    5. One of the three buttons is now a RESETN Button
    6. Libraries updated, all ICs now includes the tiny circle denoting its direction
    7. Schematics beautified and a bigger RoboBuzz
    [lec-buzzer_alt.brd, lec-buzzer_alt.sch]
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2018-07-21 Started schematic for training board based on atmega328p
    [Training_Board.sch]
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2018-08-03 Fixed pins, added VCC, changed some names
    [Training_Board.sch]
2018-08-05 Routed Electrical Training board
    [Training_Board.brd, Training_Board.sch]
2018-08-09 Routed with larger trace widths and corrected pinouts
    [Training_Board.brd, Training_Board.sch]
2018-08-09 Replaced Thru-Hole with SMD Button
    [Training_Board.brd, Training_Board.sch]
2018-08-10 Moved components around to match structure of Huzzah/Trainii
    [Training_Board.brd]
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2018-09-30 Board Changes
    Made the name space bigger, remove thermal traces, rev board, round corner, move to origin
    [Training_Board.brd, Training_Board.sch]
2018-10-01 edited graphics and finished lab guide in LaTeX
    [Hookup Schematic.sch]
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2018-10-02 Fixed issue shorting power and ground on stop method lab 1
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2018-10-03 Small DRC corrections and new gerbers
    [Training_Board.brd, Training_Board.sch]
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2018-10-22 Added Fritzing files for week 3 worksheet example circuit
    [breadboard_example.fzz]
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2019-08-07 Added eagle-libraries as submodule and created blank files for schematic and board
    [training_board.brd, training_board.sch]
2019-08-12 Preliminary Schematic completed. Components arranged and not routed on board.
    [training_board.brd, training_board.sch]
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2019-09-21 Updated Routing, added decoupling capacitors, and added silkscreen
    [training_board.brd, training_board.sch]
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2019-10-27 Fixed Stylistic issues and parts associations
    [training_board.brd, training_board.sch]
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2019-11-13 Fixed typo in BOM
    [Board_Components.csv]
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2020-04-01 Version 1.1 of Eagle Guide 2020
    *General typos and clarifications
    *Clarified installation
    *Change Eagle to EAGLE
    *Updated commands to newer eagle version
    *Spelling fixes
    *Added mention to style guide
    *Clarified board export
    *Added version history
2020-05-09 Removed 1 motor driver chip from training board
    [training_board.brd, training_board.sch]
2020-05-09 Fixed reset issue and adjusted traces:
    [training_board.brd, training_board.sch]
2020-05-10 Updated board version and removed old image and gerbers
    [Board_Components.csv, training_board.brd, training_board.sch]
2020-05-10 Finished 1.3 rev silkscreen and layer fixes
    [training_board.brd, training_board.sch]
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2020-05-20 Adjusted board to fix silkscreen overlapping pads
    [training_board.brd]
2020-05-28 Fixed extra via and wire stub
    [training_board.brd]
2020-06-06 First draft of training board schematic, re-organized for two training board
    [firmware_electrical_training_board.brd, firmware_electrical_training_board.sch, training_board.brd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]
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2020-06-09 General Improvements
    Debouce explain, button pins, MPU indicator
    [firmware_electrical_training_board.brd, firmware_electrical_training_board.sch]
2020-06-14 Fixed Resistor array part and changed orientation of LEDs.
    [firmware_electrical_training_board.brd, firmware_electrical_training_board.sch]
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2020-07-05 Fixed angled routing
    [firmware_electrical_training_board.brd, firmware_electrical_training_board.sch]
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2020-07-28 Fixed minor schematic notes, board silkscreen, and trace widths
    [firmware_training_board.brd, firmware_training_board.sch]
2020-08-03 fixed right angle trace
    [firmware_training_board.brd]
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2020-08-04 Moved 2 vias to avoid DRC
    [firmware_training_board.brd]
2020-08-04 Fixed silkscreen alignment
    [firmware_training_board.brd]
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2020-10-07 Fixed soldering training board resistor to common value
    [training_board.brd, training_board.sch]
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2020-11-19 last minute board fixes
    [training_board.brd]
2020-11-19 Fixed font and ERC
    [training_board.brd, training_board.sch]
2020-11-19 Fixed wrong layer text
    [training_board.brd]
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2020-11-19 Fixed minor issues and made roboBuzz bigger
    [training_board.brd, training_board.sch]
2020-11-19 Fixed version
    [training_board.brd]
2021-09-20 Updated for 2021-2022 training
    Deleted all presentation and lab files from 2020-2021 training and added Week 0 slides for 2021-2022 training.
    [firmware_electrical_training_board.sch, week3_electrical_training.sch]
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2023-10-12 Finalize changes for week 3 and add latex for week 2 and week 3
    [week-3-schematic.kicad_sch, week-4-schematic.kicad_sch, week3-electrical-training.kicad_sch]
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2023-10-18 Fix schematic with fixed symbol
    [week-4.kicad_pcb, week-4.kicad_sch]
2023-10-25 Convert soldering training board from EAGLE to KiCad
    [training_board.brd, training_board.csv, training_board.kicad_pcb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]
2023-10-30 Add solution to week 4 lab and finish conversion of soldering training board from EAGLE to KiCAD
    [training_board.brd, training_board.kicad_pcb, training_board.kicad_sch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]
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
